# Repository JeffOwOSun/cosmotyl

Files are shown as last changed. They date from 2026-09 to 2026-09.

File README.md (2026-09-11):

# Cosmotyl

A Python + OpenSCAD generator for a split ergonomic keyboard with curved,
floating key plates, a three-key thumb pod, and a flat base with screw columns.
The default layout has **29 keys per half**: 26 finger keys and 3 thumb keys.

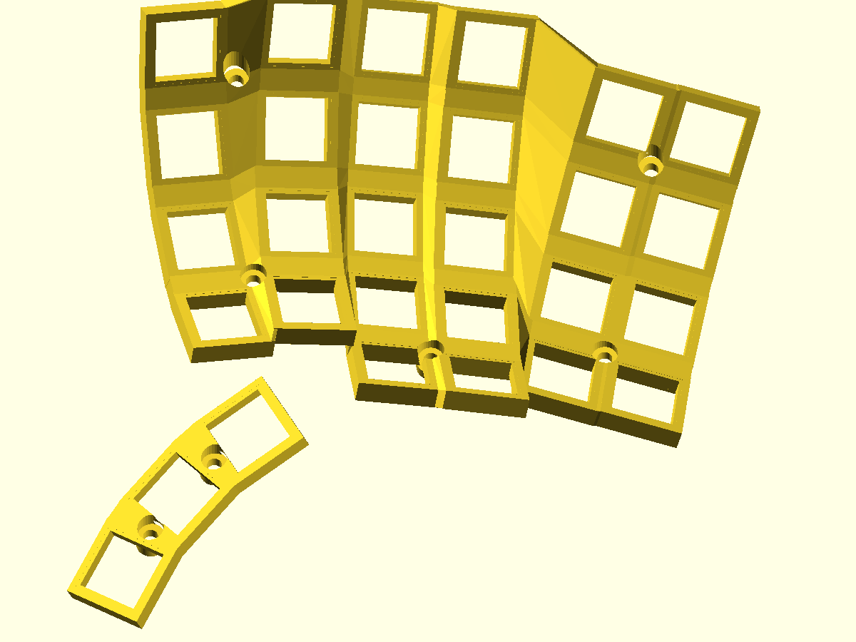
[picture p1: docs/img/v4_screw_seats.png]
Cosmotyl v4 repaired screw seats


The current v4 design prints as three parts per half: a finger sheet, a thumb
pod, and a base. Each screw recess has a continuous 3.4 mm thick bearing pad;
matching columns end 0.15 mm below the pad. The generated and exported meshes
pass closed-surface, bearing-seat, switch-envelope, screw-head, and assembly
interference checks. See [validation notes](docs/validation.md).

This remains a prototype: electronics mounting, wrist-rest integration, and
physical print/assembly trials are unfinished. The overhang heuristic still
flags one patch on the finger sheet. Earlier v1 and v3 source generators are
kept for reference; their obsolete STL exports have been removed.

## Explore the design

Download or clone the repository and open
[`output/keywell_viewer.html`](output/keywell_viewer.html) in a WebGL-capable
browser. It embeds the meshes and three.js and works offline. Drag to orbit,
scroll to zoom, and use the controls to inspect the parts, mirrored left half,
switch envelopes, and thumb placement geometry. Top and base have separate
toggles. GitHub's HTML file view shows source; download the file to run it.

## Generate

Python 3.10+ is required. The v4 mesh pipeline uses Manifold and NumPy to
preserve solid topology through Boolean operations and binary STL export.
The build evaluates the same literal geometry it writes to SCAD. OpenSCAD is
optional for inspecting that SCAD and required for the historical v1/v3 builds.

From the repository root:

```bash
python3 -m venv .venv
source .venv/bin/activate
python3 -m pip install -r requirements.txt
python3 src/verify.py          # keycap collision and bay headroom checks
python3 src/main4.py --fast    # check layout and write SCAD, no renderer needed
python3 src/main4.py           # mesh v4, verify seats/clearances, split print parts
python3 src/gen_viewer.py      # rebuild the offline viewer
python3 src/gen_viewer.py --prebuilt # use only the published example meshes
python3 -m unittest discover -s tests -v
```

Generators write working SCAD/STL files beside the sources in `src/`; these
are ignored by Git. The viewer prefers these fresh meshes and falls back to
prebuilt files in `output/`. After changing the layout, regenerate v4 before
rebuilding the viewer.
`--prebuilt` uses the checked-in example meshes exclusively.

Historical builds require OpenSCAD on `PATH`, in the standard macOS app
location, or configured through the `OPENSCAD` executable path:

```bash
python3 src/main3.py --fast    # omit --fast to render the v3 body
python3 src/main.py --fast     # omit --fast to render v1 case/base/wrist
python3 src/main.py --preview # also render preview PNGs (display required)
```

## Customize

Edit [`src/config.py`](src/config.py). All dimensions use millimeters and
angles use degrees. The canonical right half has +X toward the pinky, −Y
toward the user, and +Z upward.

- `COLUMNS`: column position, splay, travel, and row count.
- `THUMB`: anchor offset, orientation, fan radius, and angular spacing.
- `CASE`: tent, slope, lift, socket dimensions, and base thickness.
- `BATTERY` and `WRIST`: legacy bay probes and wrist-rest dimensions.

The preset derives from hand measurements adjusted for geometric clearance.
Raw traces and personal comfort analysis are excluded; the design dimensions
remain to reproduce the supplied model. See the
[measurement method](docs/hand_geometry_report.md).
The v4 screw sites in `main4.py` assume the included column layout and must be
reviewed when changing the column or row counts.

Each column follows a circular arc with radius `clamp(travel * 1.4, 55, 75)`.
Splay changes orientation while the home-row position stays on its target.
Global tent and slope are applied before a calculated floor-clearance lift.
The thumb keys follow a manually tuned 85 mm circular fan about a wrist-side
pivot; the viewer exposes its anchor, offset, plane, and spokes.

## Printing and assembly

The included v4 meshes are:

| File | Purpose |
|---|---|
| [`base4_right.stl`](output/base4_right.stl) | Base, flat side down; seven integral columns |
| [`top4_print_board.stl`](output/top4_print_board.stl) | Finger sheet rotated onto its side |
| [`top4_print_pod.stl`](output/top4_print_pod.stl) | Thumb pod rotated onto its side |
| [`top4_right.stl`](output/top4_right.stl) | Both upper parts in assembly coordinates |

Mirror the right-hand parts in the slicer for a left half. Inspect overhangs
and bed contact in the slicer before printing: the area/patch checks are
heuristics, and one patch on the finger sheet remains unresolved.

The modeled hardware per half is 29 MX-style switches with XDA caps and seven
3.0 × 12 mm thread-forming screws with pan heads. Screws enter from above
before switches are installed; columns have 2.5 mm pilot bores and 6 mm necks.
The 6 mm counterbores have uninterrupted bearing rings around the 3.4 mm
clearance holes. Screw-head seats are lowered 0.4 mm from the original design.
Use the updated base together with the updated upper parts.
Check actual switch and screw dimensions against the model. The legacy
battery envelope is 50 × 35 × 6.5 mm with a XIAO-class controller; the v4 base
does not yet contain physical electronics pockets or mounts.

## Checks and limitations

- `verify.py` rejects collisions in a simplified two-slab keycap OBB model
  and inadequate sampled bay headroom. It does not model every real keycap.
- Full v4 builds require empty intersections for top/switch, base/switch,
  top/base, and all seven screw heads against the switch/cap/travel envelope.
  A 0.05 mm envelope clearance is cut into the upper sheet. `--fast` skips mesh
  checks. Historical builds still reject OpenSCAD errors and warnings.
- The exporter checks every edge for closure and consistent winding before
  and after splitting the top into two print files. Vertical material probes
  check all seven bearing rings, clear shafts, and the matching column seats.
  CI checks the published files and performs a complete v4 build.
- Orientation and flat-down patch audits report potential print issues; they
  do not establish that a printer can produce the part without supports.
- The v1 wrist rest is not fitted to the v4 base. No dedicated left STLs,
  electronics integration, wiring layout, PCB, or firmware are provided.

## Source map

| Module | Role |
|---|---|
| `config.py`, `placement.py`, `transform.py` | Parameters, key frames, matrix math |
| `main4.py` | Current base, screw seats, upper sheet, print export and audits |
| `main3.py`, `main.py` | Earlier rod-supported and walled variants |
| `web.py`, `skirt.py`, `bottom.py` | Plate connections and legacy case geometry |
| `wrist.py`, `electronics.py` | Legacy wrist rest and electronics features |
| `verify.py`, `devtool.py`, `render.py` | Layout checks, switch envelopes, legacy OpenSCAD rendering |
| `mesh_backend.py`, `mesh_audit.py`, `stl_io.py` | Robust CSG evaluation, topology/seat checks, binary STL I/O |
| `stl_components.py`, `stl_clean.py` | Mesh component inspection and sliver removal |
| `gen_viewer.py`, `viewer.css`, `vendor/` | Offline viewer generation |

`docs/` contains historical design and research notes, including abandoned
experiments. Their older verdicts are not current verification results.

The retained `devtool_right.stl` is the switch-envelope inspection asset used
by the offline viewer and validation; it is not a printed part.

## Acknowledgments

The research notes study [Cosmos Keyboards](https://github.com/rianadon/Cosmos-Keyboards),
[Dactyl](https://github.com/adereth/dactyl-keyboard), Dactyl-Manuform, and
Dometyl placement and geometry approaches. Their names and source references
are retained in the notes. Cosmotyl is an independent project.

The mesh pipeline uses [Manifold](https://github.com/elalish/manifold) for
solid modeling. The viewer vendors three.js r147 under MIT; its full notice is in
[`src/vendor/three.LICENSE.txt`](src/vendor/three.LICENSE.txt) and embedded in
the generated HTML. See [third-party notices](THIRD_PARTY_NOTICES.md).

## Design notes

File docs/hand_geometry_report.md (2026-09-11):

# Layout preset and measurement method

The default in [`src/config.py`](../src/config.py) is a scan-derived example
layout. Its design dimensions are retained so the included meshes can be
reproduced. Raw hand traces and personal comfort analysis are not distributed.

Each finger trace was approximated by a line to estimate column position,
splay, and comfortable travel. Those inputs were adjusted for keycap clearance
before becoming the column table. Travel controls the bounded bowl radius and
column height; it is not a guarantee of reach or comfort for another hand.

To customize the layout, edit `COLUMNS`, `THUMB`, and `CASE` in `config.py`,
run the geometry checks, and inspect the generated model. The thumb fan is a
manually tuned circular approximation. Physical fit and print quality still
need to be checked on a prototype.

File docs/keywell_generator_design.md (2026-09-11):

# Keywell Generator — Architecture & Design

> Historical design notes. Some experiments and referenced artifacts are not
> included in this repository; see the root README for the current build.

A standalone Python → OpenSCAD procedural generator for the Cosmotyl split keyboard,
replacing Cosmos (whose rounded walls + wrist-rest solid are PRO-locked). Design follows
your 8-step pipeline, with every default traced to a source: **[C]** Cosmos internals
([cosmos_internals.md](research/cosmos_internals.md)),
**[M]** Dactyl Manuform, **[D]** Dometyl
([generator_patterns.md](research/generator_patterns.md)),
**[U]** our scan/collision-verified values
(gen_case.py (historical artifact, not included)).

## Core architectural decisions

1. **Stack**: Python emitting OpenSCAD (like your Clojure→scad experience; OpenSCAD is
   already installed and `gen_case.py` proves the workflow). Pure-functional style:
   placement math returns 4×4 matrices; solids are emitted separately.
2. **The one non-negotiable pattern — place/position duality [M]**: a single function
   `key_frame(col, row) -> Mat4` feeds BOTH solid placement and point queries
   (`key_position(col, row, local_pt) -> Vec3`). Thumb anchor, screw sites, wall starts,
   wrist footprint, USB port — all consume this one function, never re-derive. This is
   manuform's `apply-key-geometry` trick and the reason its thumb follows the well
   automatically.
3. **Coordinates [C]**: mm, degrees, **Z-up**, right-handed; key local frame +Z out of
   the cap; each key frame lands at **socket top center**. Right half canonical, left =
   mirror. (This drops gen_case.py's y-up design frame — one frame end to end, no
   rotate([90,0,0]) at the tail.)
4. **Hollow shell (Charybdis-style)**: NO vertical extrusion of the keywell perimeter.
   The case = thin web shell (thickness ≈ socket height) + swept perimeter walls only
   where structurally needed + interior pillars that double as heat-insert bosses.
5. **Rich intermediate results [D]**: each stage returns geometry + metadata (wall foot
   quads, continuous `outline`/`inline` ground paths). The bottom plate and wrist rest
   are then ~10-line consumers of the outline — never modeled independently.

## The 8-step pipeline, concretely

### 1. Ground the home row
World origin = home-row key of the **middle column**, socket top center, cap facing +Z.
Every other key is placed relative to this. (Cosmos centers on `centerRow = nRows-3`,
same idea [C§1]; manuform `centerrow = nrows-3` [M].)

### 2. Grow the fingers cluster
Per-column dataclass `Column{name, offset(x,y,z), splay, radius_or_travel, rows}` —
layout-as-data, dometyl `Lookups` style [D§7.2]. Placement for key (c, r):

```
key_frame(c,r) = Splay_c · T(offset_c) · ArcRow(r - home_row)
ArcRow(k):  R_c = clamp(1.4·travel_c, 55, 75)            [U, scan-derived]
            Δθ_c = max(18.5/R_c, 18.9/(R_c - 7))          [U, collision-verified]
            rotate -k·Δθ_c about X through [0, 0, R_cap], R_cap = R_c + cap_top
```

- Pivot about the **finger-contact sphere** (`+ cap_top` on the radius): cap_top = 6.2
  (MX unpressed) + 9.9 (XDA) ≈ 16.1 mm [C§2] (Clojure uses plate 4 + SA 12.7 = 16.7 [M]).
- **Splay rotates about the cluster origin** (cumulative γ), not the column's own axis
  [C§2] — this is what Cosmos does and what our `inject_splay.py` already encodes.
  Values: +10.7 / +4 / 0 / −1.5 / −11.4 / −11.4 (non-negotiable).
- Column staggers from your hand scan (gen_case.py L9-16 table, re-expressed in Z-up).
- Row curvature is per-column via `Δθ_c` (deeper bowl for longer fingers), replacing
  fixed α=15°; no cross-column arc — columns are placed by offset+splay like [U]/[D],
  not on a second sphere.

### 3. Grow the thumb cluster (pointing into the ground is fine)
Anchor **through the pipeline** [M§2.2], never absolute:

```
thumb_origin = key_position(inner_col, bottom_row, [+w/2, -h/2, 0]) + tuned_offset
thumb_frame(i) = T(thumb_origin) · Rz(yaw) · Ry(roll) · Rx(pitch) · T(key_i_offset)
```

Seed pose = the Cosmos Curved-3 pose we already ship, converted into this anchored form
(Cosmos values: (−35.78, −25.67, −7.08) mm / (−11.9°, −24.8°, 34.4°) [C§3], plus our
(−4, −6, 0) nudge). 2 keys initially (matching the accepted design), sculpt table
available for more.

### 4. Orient: tenting + backward rotation — applied ONCE
`Orient = T(0,0,lift) · Ry(-tent) · Rx(-slope)` applied at the single tail of
`key_frame` [M§6], so every point query inherits it. `tent = 12°` canonical.
`lift` is **computed**: scan all socket/cap corner points, `lift = clearance − min_z`
[D§6] — no magic z constants. Unlike Cosmos, the thumb is anchored (step 3), so
re-tenting moves it correctly for free — fixing Cosmos's tent-slider-ignores-thumb wart.

### 5. Thin shell: curved plate + minimal lofted skirt (NO walls) — per your call
- **Web (the case itself)**: 0.1 mm corner posts + triangle-hulls between
  row/col/diagonal neighbors [M§3] (gen_case.py already does this); thickness = socket
  height 4.7 mm [C§7], top flush with socket top. The doubly-curved 4.7 mm plate is the
  structural shell — no perimeter walls, no vertical extrusion of the keywell.
- **Support skirt**: a thin ruled loft from the plate's boundary edge straight down to
  the z=0 construction plane — each boundary edge segment hulled with its own floor
  projection (this degenerates dometyl's bezier sweep to d1=d2=0; the foot outline
  falls out for free). Thickness 2 mm; its only jobs are (a) a flat printable rim,
  (b) carrying the USB-C slot, (c) hosting the insert bosses, (d) hiding electronics.
  Boundary detection: flat-project socket corners → concave hull [C§6], or directly the
  known edge list from the grid (gen_case.py `boundary_edges`).
- **Pillars**: vertical struts from web underside to floor at the heat-insert sites
  (step 6) + under the thumb pod — pillars ARE the bosses, no separate ribs.
- **Rounded top edge**: with no wall band, this reduces to rounding the plate's exposed
  boundary edge — chamfer/roundover ring swept along the boundary loop (cheap,
  printable, no minkowski of the whole solid).
- **Thumb↔body seam**: explicit configurable link (universal hard part [D§7-pitfalls]);
  v1 = triangle-hull bridge like gen_case.py L169-174, kept as its own module; the
  thumb pod gets its own skirt loft to the same plane.

### 6. Bottom plate — a projection, aligned by construction
`plate = linear_extrude(2.5) polygon(outline_2d)` where `outline_2d` = the skirt's foot
outline recorded in step 5 (dometyl `Connect.outline` [D§5.3]; equivalently manuform's
`cut` at z≈0 [M§5.2]). Heat-insert bosses (M3: bore Ø4.0 for insert, boss Ø8, h 6)
placed along the skirt's inner foot path; the plate's screw holes reuse the **same site
list** — alignment is guaranteed because both consume one data structure. 5 sites:
back-left, back-right, front-right, front-middle, thumb-side. (Resolved: 5× M3 heat
inserts, per your OK.)

### 7. Electronics in the BASE, not the shell
- **XIAO nRF52840** bay: PCB 21×17.8×3.4 (+USB-C overhang ≈1.3); printed rails on the
  bottom plate hold it; USB-C slot (9.5×3.6, chamfered) cut through the back skirt at a
  height computed from `key_position` of the back boundary edge — one port per half,
  no TRRS (your accepted design).
- **Battery** pocket sized for your actual cells (screenshots): **EEMB LP603449
  49×34×6.0 mm 1100 mAh** (design driver) and **522332 32×22×5.2 mm 400 mAh** (fits the
  same pocket). Pocket 50×35×6.5 with a strap bar + JST-PH 2.0 pigtail channel,
  positioned under the middle-column web where step-2 clearance analysis
  (gen_case.py L108-132 shows ≥ bay height) says it fits.
- Both live on the bottom plate → swap/repair without reprinting the shell.

### 8. Wrist rests — with real clearance
Port Cosmos's OPEN footprint algorithm [C§5]: case-side edge from actual wall outline
points, front edge = `min_y + extension (80 mm)`, taper 10°, maxWidth 100. Then the two
things Cosmos can't do:
- **`clearance` parameter = 1.0 mm**: offset the case-side edge away from the case along
  the local outline normal before building the solid — pad drops in/out freely.
- Solid generation ourselves (PRO in Cosmos): extrude footprint, apply slope 5° + WR
  tent 6° [C§5 defaults], `minkowski` a small sphere on the top face for the rounded
  comfortable edge, flat bottom.
- Pad ends at the **middle-column line** (your earlier requirement), position seeded
  from the accepted (+52, 0, −18) offset.

## Defaults table (provenance-tagged)

| Parameter | Value | Src |
|---|---|---|
| Key pitch (row, arc chord) | 18.5 mm | U |
| Cap-base clearance rule | Δθ = max(18.5/R, 18.9/(R−7)) | U |
| Column radius | clamp(1.4·travel, 55, 75) | U |
| cap_top (MX + XDA) | 6.2 + 9.9 = 16.1 mm | C |
| Splay (inner→outer) | +10.7, +4, 0, −1.5, −11.4, −11.4 | U |
| Tent / lift clearance | 12° / computed, ≥ 8 mm interior | U |
| MX cutout | 14.15 mm (print shrink) + 1.4 mm clip undercut | U |
| Socket (plate) size | 18×18, height 4.7 mm | C |
| Web thickness | = socket height (4.7) | C |
| Skirt thickness | 2 mm (ruled loft, boundary → z=0) | you |
| Boundary edge roundover | r 1.5 mm ring along boundary loop | D (adapted) |
| Bottom plate | 2.5 mm | D (1.65) → thicker for bays |
| Heat inserts | M3, bore Ø4.0, boss Ø8×6; 5 sites | M/C, OK'd |
| Battery pocket | 50×35×6.5 (LP603449; 522332 fits) | you |
| Wrist ext / taper / maxW / slope / WR tent | 80 mm / 10° / 100 mm / 5° / 6° | C |
| **Wrist↔case clearance** | **1.0 mm** | **you** |

## Module layout (`scratch/keywell/`)

```
config.py      # dataclasses: Column, Thumb, Case, Wrist — the whole design as data
transform.py   # Mat4 helpers (from gen_case.py), frame composition
placement.py   # key_frame / key_position / thumb_frame + lift computation
verify.py      # OBB keycap collision (ported), bay clearance, skirt-foot sanity
web.py         # posts + triangle-hulls
skirt.py       # ruled loft boundary→plane, foot outline, edge roundover
bottom.py      # plate from outline, bosses, screw holes
electronics.py # XIAO rails + USB slot + battery pocket
wrist.py       # footprint + clearance offset + solid
emit.py        # SCAD emission; scene = union of parts
main.py        # build right half, mirror left, render STLs, run verify
```

## Verification plan (each iteration)

1. `verify.py` gates: 0 keycap OBB collisions; bay clearances ≥ spec; every skirt foot
   lands at z=0; outline is simple (no self-intersections).
2. `openscad -o` renders both halves + plate + wrist → STLs into the working directory.
3. Rebuild the three.js viewer from the new STLs (existing `gen_cosmos_viewer.py`
   pipeline) → visual check with screenshots, including the 1 mm wrist gap measured on
   a cross-section (existing junction-section tool).

## Resolved decisions (2026-09-10)

1. **Shell style**: NO walls — curved plate + minimal 2 mm skirt lofted to the z=0
   construction plane, purely for a flat printable bottom (your call).
2. **Fastening**: 5× M3 heat inserts, OK'd.
3. **Battery**: EEMB LP603449 (49×34×6.0, 1100 mAh) drives the pocket; 522332
   (32×22×5.2, 400 mAh) fits the same pocket (your screenshots).

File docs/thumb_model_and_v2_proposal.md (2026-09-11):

# Thumb Placement Model + v2 Pipeline Proposal

> Historical design notes. Some experiments and referenced artifacts are not
> included in this repository; see the root README for the current build.

Deliverable for feedback items #4–#6 (2026-09-10). Sources: [thumb_placement_models.md](research/thumb_placement_models.md) (Dactyl/Manuform/Dometyl/Cosmos source analysis, file+line cited) and [thumb_kinematics_web.md](research/thumb_kinematics_web.md) (biomechanics + community literature).

## 1. The thumb placement model (#4)

**Recommendation: a planar circular fan arc about the CMC pivot, anchored through the finger pipeline.** This is simultaneously the biomechanically correct model and the one the best-engineered generator (dometyl) uses.

Why this is the right curve, not just a convenient one:

- With the palm planted, pure thumb flexion–extension is rotation about ONE fixed axis in the trapezium (Hollister et al. 1992), so the thumb tip traces a **circle** — the anatomically exact curve for a key row reached by the cheapest 1-DOF motion.
- The exact anatomical refinement (two skew axes, ~124° apart, ~9.2 mm offset) collapses to the same circle within <1.5 mm over a 3-key sweep, so nothing fancier is justified.
- Comfortable sweep radius from HCI research: **63–76 mm** (CHI 2014 thumb-area studies); dometyl ships R = 85; our scan's straight-looking 42 mm trace is consistent with any R ∈ [70, 100] (sagitta at R = 85 over 42 mm is only 2.6 mm — below trace noise).
- Every project that beats hand-tuned offsets uses exactly this: dometyl's fan (R = 85, 14.4°/key about a fixed center), Cosmos `placeOnSphere` (same thing plus dome curvature), Keyboardio's physical "thumb arc".

### The expression

**Anchor — derived through the pipeline, never absolute** (the Manuform/Cosmos pattern; this is what makes the cluster follow stagger/curvature/tent changes automatically):

$$A = M_{\text{index,bottom}} \cdot T(-29, -30, 0)$$

where \(M_{\text{index,bottom}}\) is the world frame of the index-column bottom key and (−29, −30) mm is **your measured thumb-rest offset** from the hand scan.

**Cluster frame** (heading measured, tilts converged from 3 projects):

$$F = A \cdot R_z(-37°) \cdot R_y(\beta_t) \cdot R_x(\alpha_t) \cdot T(0,0,z_t)$$

with your measured −37° arc heading; β_t = −25° roll toward the thumb pad (Manuform −23…−35°, Cosmos Curved −24.8°, dometyl −20° all converge here); α_t = +10° pitch; z_t = −7 mm drop.

**The curve** (in frame F, arc center on the palm side approximating the CMC pivot):

$$C(\theta) = \big(R\sin\theta,\; R(1-\cos\theta),\; 0\big), \qquad R = 85\text{ mm (tunable 70–100)}$$

**Moving frame + key poses**: tangent \(\hat T(\theta) = (\cos\theta, \sin\theta, 0)\), normal \(\hat N\) pointing at the arc center, binormal \(\hat B = \hat z_F\):

$$M_i = F \cdot [\hat T(\theta_i) \mid \hat N(\theta_i) \mid \hat B \mid C(\theta_i)] \cdot R_{\hat T}(\rho_i), \qquad \theta_i = (i - i_{\text{home}}) \cdot p / R$$

with key pitch p = 20 mm (current thumb pitch) → 13.5°/key, matching dometyl's 14.4° and the biomechanical 14.6° at R = 75. Optional cup roll ρ_i = −10°·(i − i_home) tilts outer keys toward the pad (upgrade path = Cosmos dome).

**Sanity checks built in**: 3-key span = 2p = 40 mm ≤ your measured 42 mm comfortable span; total sweep 27° ≤ 35° budget (⅔ of the 53° FE range of motion); home key at the rest pose θ₀, not mid-arc.

**Free parameters and their status**: measured — anchor (−29,−30), heading −37°, span budget 42; defaulted-but-bounded — R = 85 ∈ [70,100], β_t = −25°, α_t = +10°, z_t = −7, ρ = 0. The devtool collision gate + your visual review tune the last four.

## 2. Connector generation by sweep (#5)

Exactly your procedure, expressed against C(θ). Right-half frame (mirror of your left-hand description — the innermost thumb key's inner face points toward **+x**/the main board):

1. Place thumb keys on C(θ), loft adjacent keys into a single row (pairwise hulls along \(\hat T\)).
2. Take the **inner side face** of the innermost key t0: the rectangle at local +HW spanning the socket depth and plate thickness.
3. **Sweep** that profile along C(θ) extended past θ₀ (toward the board): sample θ at 2–3° steps, place the profile with the moving frame at each sample, hull consecutive profiles.
4. Stop when the swept profile is fully inside the main body; **cut** the overlap (boolean subtract body), keeping the sweep watertight against it.
5. Loft/fillet the seam ring where the sweep meets the body.

Because the sweep follows the same curve the keys sit on, the connector is tangent-continuous with the thumb row by construction — no more misaligned loft between unrelated frames (the current index→pod hulls).

## 3. v2 pipeline (#6) — Bezier-surface body

Restating your algorithm with implementation specifics:

| Step | What | Implementation notes |
|---|---|---|
| A | Solid (hole-less) socket blocks at every key pose (fingers + thumb on C(θ)) | trivial change: today's plates without the hole cut |
| B | Loft into a continuous reference solid | today's hull machinery, but between full blocks → every face continuous; this reference defines the **bottom** and the minimum top |
| C | Bezier control net: one control curve per column (control points at that column's socket centers + normal offset), rows roughly x-aligned; tensor-product patch evaluated on a dense grid → polyhedron | pure Python; no CGAL needed for surface eval |
| D | Thumb cluster columns join the net as additional control columns (via C(θ) frames) | the surface flows over the connector region — this is what makes the seam smooth |
| E | Verify surface ≥ reference top everywhere (sample reference top corners against patch; push control points up where violated); body = volume between patch and B's bottom | iterate until zero violations |
| F | Cuts in order: (1) flat mount pocket per key (key_w × key_d, normal to key frame, down to socket-top plane — restores the flat seat + the ~1.5 mm clip thickness MX needs), (2) 14.15 through-hole + clip undercut, (3) bottom hollow | pocket before hole, exactly as you specified |
| G | Gate: `intersection(body, devtool) = ∅` where devtool = switches + XDA caps + 4 mm travel envelopes + underside housings/pins | already built and running — today's build reports **CLEAN** |

**No walls at all** (#2): the v2 body is a thick curved slab — the skirt disappears. Consequences to sign off on: M3 bosses become pillars hanging from the slab underside to the bottom-plate plane; the XIAO + USB port mount moves to the **bottom plate** (cradle already lives there; the slot becomes a notch in the slab's back edge or a bottom-plate-mounted port); the bottom plate keeps the current foot-polygon outline.

## 4. Already done this session (items #1–#3)

- **3-key thumb**: config + web + skirt generalized; build is green with 0 keycap collisions.
- **Devtool**: switches + caps + travel envelopes render as a translucent red toggle in the [viewer](../output/keywell_viewer.html), and the build now runs the intersection gate — currently **CLEAN** (even the ugly seam doesn't invade any switch/cap volume; it's an aesthetic/printability problem, which v2's surface fixes properly).

## Decision requested

1. **Thumb model**: planar fan arc as specced (R=85 default, pipeline anchor, your scan's −29/−30/−37°) — OK to implement?
2. **v2 pipeline**: proceed with A–G as tabled, replacing the current web+skirt entirely?
3. **Electronics relocation** (consequence of no-wall): XIAO/USB on the bottom plate, bosses as underside pillars — OK?

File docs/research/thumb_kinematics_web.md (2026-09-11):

# Thumb Motion Models for 3-Key Thumb Cluster Placement — Web Research

> Historical design notes. Some experiments and referenced artifacts are not
> included in this repository; see the root README for the current build.

Research date: 2026-09-10. All web-sourced; inline URLs per claim. Confidence notes marked where a number comes from secondary summaries rather than the primary paper text.

## 1. Accepted kinematic model of thumb-tip motion

**The consensus biomechanical model treats the trapeziometacarpal (CMC/TMC) joint as 2 rotational DOF about two FIXED, NON-ORTHOGONAL, NON-INTERSECTING (skew) axes**, established by Hollister, Buford, Myers, Giurintano & Novick, *"The axes of rotation of the thumb carpometacarpal joint"*, J. Orthop. Res. 10(3):454–460, 1992 ([paper via Google Scholar](https://scholar.google.com/scholar?q=%22The+axes+of+rotation+of+the+thumb+carpometacarpal+joint%22+Hollister)). Their key findings:
- The **flexion–extension (FE) axis is fixed in the trapezium**; the **abduction–adduction (AA) axis is fixed in the first metacarpal**; neither axis is perpendicular to the bones or to each other ([PubMed summary](https://pubmed.ncbi.nlm.nih.gov/?term=Hollister+axes+rotation+thumb+carpometacarpal)).
- Follow-up modeling literature quantifies the skew as an inter-axis angle of ≈124° (SD ≈19°) with an inter-axis offset of ≈9.2 mm (numbers from later studies building on Hollister's method, surfaced in an NIH-indexed source during search — treat as representative, verify against the specific paper before publishing). Because the axes are fixed and skewed, the articular surfaces behave like **"skewed tori"** rather than an orthogonal saddle.
- The joint additionally exhibits coupled **pronation–supination (axial rotation)**: Cooney, Lucca, Chao & Linscheid, *"The kinesiology of the thumb trapeziometacarpal joint"*, JBJS 63-A(9):1371–1381, 1981 ([Scholar](https://scholar.google.com/scholar?q=Cooney+kinesiology+thumb+trapeziometacarpal+joint+1981)) measured average TMC ROM of **53° flexion–extension, 42° abduction–adduction, 17° axial rotation** via roentgenographic markers. The 17° axial rotation is largely kinematically coupled to FE/AA (it is what lets the pad "oppose"), which matters for key-top orientation.
- Robotics confirms the skew-axis requirement: the CMU **ACT (Anatomically Correct Testbed) hand thumb** (Chang & Matsuoka, *"A Kinematic Thumb Model for the ACT Hand"*, ICRA 2006, [CMU RI page](https://www.ri.cmu.edu/publications/a-kinematic-thumb-model-for-the-act-hand/)) is a **5-DOF serial chain (2 CMC + 2 MCP + 1 IP) with deliberately non-orthogonal, non-intersecting axes**, and the same group showed that simplified orthogonal/intersecting-axis thumb models **mispredict the tip workspace and endpoint forces** — the direct argument for not modeling the thumb as a gimbal.

**What curve does the TIP trace with the palm planted?**
- Pure FE at the CMC (distal joints held) is rotation about ONE fixed axis, so the tip traces a **circular arc lying in a plane perpendicular to the FE axis**, with radius = perpendicular distance from tip to that axis. This is why circle/sphere fitting to motion-capture thumb-tip trajectories is a standard technique for locating the functional pivot and radius of curvature (e.g., sphere/circle-fitting of thumb-tip workspaces in reachable-workspace studies, [UCSF/eScholarship workspace modeling](https://escholarship.org/), [markerless mocap CMC studies on PMC](https://www.ncbi.nlm.nih.gov/pmc/)).
- **Plane orientation relative to the palm:** classical hand anatomy (Kapandji; standard kinesiology references, e.g., [OUHSC hand kinesiology notes](https://www.ouhsc.edu/bserdac/dthompso/web/namics/thumb.htm)) defines thumb **flexion–extension as occurring in a plane roughly PARALLEL to the palm** (thumb sweeps across the palm) and **palmar abduction–adduction in a plane roughly PERPENDICULAR to the palm**. So to first order the FE axis ≈ palm normal — but Hollister's result says it is oblique, tilted away from the exact palm normal and not orthogonal to the AA axis, so the real FE arc plane is **tilted ~10–25° from palm-parallel and the arc plane also rides ~1–2 cm above the desk when the palm is planted** (tilt magnitude is my synthesis of "non-orthogonal, non-perpendicular-to-bones"; the papers give axis orientations relative to bone landmarks, not the palm plane — a hand scan should FIT this tilt rather than assume it).
- Full 2-DOF **circumduction traces a cone-like closed loop**, i.e., the tip moves on an approximately spherical/toroidal shell around the CMC region ([PMC review of CMC kinematics](https://www.ncbi.nlm.nih.gov/pmc/), thumb-workspace modeling literature above). With skew offset axes the exact shell is a **torus patch** (offset d≈9 mm between axes), which for a 3-key cluster is indistinguishable from a sphere of radius R±d.
- **Quantitative tip-sweep radius from HCI research:** for one-handed phone grips, the comfortable thumb sweep is an **arc of ≈63–76 mm (2.5–3 in) radius about the thumb base**, with extreme reach measured up to **97.5 mm** (Bergström-Lehtovirta & Oulasvirta, *"Modeling the functional area of the thumb on mobile touchscreen surfaces"*, CHI 2014, [PDF via Aalto](http://users.comnet.aalto.fi/oulasvir/pubs/)); Steven Hoober's thumb-zone work popularized the arc-shaped "natural zone" ([uxmatters series](https://www.uxmatters.com/mt/archives/2017/03/design-for-fingers-touch-and-people-part-1.php)). These radii are measured mid-flexion (bent MCP/IP), which matches the typing posture better than full-extension anthropometric thumb length (~100–120 mm from CMC).

## 2. How ergonomic keyboard designers actually place thumb clusters

**Cosmos (ryanis.cool/cosmos)** — the most explicit generator:
- The webcam **hand scan measures only phalanx bone lengths** and drives keywell row/column stagger; the docs state the fitting algorithm is "primitive" and the **thumb cluster is NOT auto-placed from scan data** ([Cosmos hand-scans docs](https://ryanis.cool/cosmos/docs/hand-scans/)).
- Thumb presets: **Manuform, Carbonfet, Orbyl, Curved**; the **"Curved" preset with 3 or 5 keys is the recommended comfort option**, and users are told to experiment with **negative curvature** ([Cosmos docs / tips](https://ryanis.cool/cosmos/docs/)). The whole cluster is moved/rotated as a rigid unit (press "P"), i.e., placement is manual 6-DOF.
- **Expert mode is the quantitative core**: thumb keys are placed with `placeOnSphere({curvature, spacing, angle, row})`, which arranges keys **along concentric circles**: `angle` = position along the circle, `row` = number of `spacing` (mm) intervals from the sphere center, `curvature` = per-step tilt so key normals stay tangent to the sphere ([Cosmos expert-mode docs](https://ryanis.cool/cosmos/docs/expert/), source: [github.com/rianadon/Cosmos-Keyboards](https://github.com/rianadon/Cosmos-Keyboards)). Main keywell uses `placeOnMatrix` (two cylinder curvatures). This is exactly a spherical-cap parameterization of the thumb fan.

**Dactyl / Dactyl-Manuform:**
- Original Dactyl (Matt Adereth, [github.com/adereth/dactyl-keyboard](https://github.com/adereth/dactyl-keyboard), talk *clojure.core/typing* [YouTube](https://www.youtube.com/watch?v=uk3A41U0iO4)) places the thumb keys on a concave well generated in Clojure like the torus-section finger wells.
- Dactyl-Manuform (Tom Short, [github.com/tshort/dactyl-keyboard](https://github.com/tshort/dactyl-keyboard)) swaps in the ManuForm thumb cluster: **each thumb key gets an individual Euler rotation `[rx ry rz]` plus translation `[tx ty tz]` from a `thumborigin` anchor near the bottom inner index-column key** (with a small global `thumb-offsets` vector); typical per-key rotations in the source are in the **±10–25° range per axis** and offsets of order 10–60 mm. There is **no underlying curve model** — the six keys are hand-tuned poses, which is exactly the pain point your model would fix ([community explanation of the rotation/translation vectors, r/ErgoMechKeyboards threads](https://www.reddit.com/r/ErgoMechKeyboards/)).

**Bastard Keyboards (Skeletyl / Charybdis, [bastardkb.com](https://bastardkb.com/)):** deliberately ship **3-key thumb clusters** (Skeletyl, Charybdis Nano) on the rationale that only keys inside the thumb's no-stretch zone should exist, with layers (Miryoku) replacing key count; on Charybdis the cluster is co-placed with the trackball so the thumb transitions between ball and keys without hand movement ([bastardkb.com product/docs pages](https://docs.bastardkb.com/)).

**Keyboardio Model 01/100 ([keyboard.io](https://shop.keyboard.io/)):** 4 thumb keys per hand arranged **along an arc under the palm** ("thumb arc") sized so adjacent modifiers can be chorded by one thumb; rationale is offloading pinkies and echoing natural thumb sweep, but no published radius — the arc was tuned through physical prototyping (Jesse Vincent's design write-ups/interviews).

**Community consensus numbers** (r/ErgoMechKeyboards, kbd.news):
- Only **1–2 thumb keys are comfortable for high-frequency use; 2–3 max are reachable without stretch**; extra keys get demoted to rare functions ([community consensus threads](https://www.reddit.com/r/ErgoMechKeyboards/), [bastardkb rationale](https://bastardkb.com/)).
- kbd.news distinguishes two schools: **"thumb blocks"** (Kinesis/ErgoDox plates) vs **"thumb curves"** (Keyboardio, Kyria, Iris) that align few keys **along the thumb's arc**; sloped/dished clusters beat flat ones; most-used key should sit ≤0.5u from the thumb's resting spot; convex keycaps preferred because the thumb strikes obliquely ([kbd.news, tags "thumb cluster"/"ergonomics"](https://kbd.news/)).
- In **Ergogen** ([docs.ergogen.xyz](https://docs.ergogen.xyz/)), thumb fans are built with per-key `rotate` around a shared origin plus `splay` — i.e., a discrete circular arc in 2D, tented afterwards.
- Practical fit check: print layouts 1:1 with [compare.splitkb.com](https://compare.splitkb.com/) and see where the thumb lands.

## 3. Projects with EXPLICIT curve parameterizations
1. **Cosmos `placeOnSphere`** — spherical cap: key i at azimuth `angle_i` on circle `row_i · spacing` from center, normal tilted by `curvature · row` to stay sphere-tangent ([expert docs](https://ryanis.cool/cosmos/docs/expert/)). The only mainstream generator with a closed-form thumb curve.
2. **Original Dactyl** — thumb keys on the same torus/cylinder-section machinery as the keywell (row radius + column radius parameters in `dactyl.clj`, [source](https://github.com/adereth/dactyl-keyboard)).
3. **Ergogen splay/rotate zones** — 2D circular fan about a declared origin ([docs](https://docs.ergogen.xyz/)).
4. **Lalboard (JesusFreke, [github.com/JesusFreke/lalboard](https://github.com/JesusFreke/lalboard)) and its commercial successor Svalboard ([svalboard.com](https://svalboard.com/))** — per-finger/thumb clusters with **5–6-DOF adjustable mounts fitted empirically** (Svalboard publishes a 5-step fit procedure: palmrest 3-axis, then per-cluster X/Y/Z/roll/yaw); users have clay-molded or 3D-scanned hands to freeze positions. **No analytic curve** — it's measured-pose capture, the empirical endpoint your model should approximate analytically.
5. Dactyl-Manuform and most forks: **no curve**, hand-tuned per-key poses (see §2).

## 4. Proposed candidate mathematical models for a 3-key cluster

Common frame: palm plane Π with origin at planted pisiform/heel, x = ulnar→radial, y = distal, z = palm normal. Let P = CMC pivot (palpable at base of thenar eminence, ~ scaphoid tubercle).

**Model A — Single circular FE arc about an oblique CMC axis (recommended default).**
K(θ) = P + R·(cosθ·u + sinθ·v), where {u,v,n} orthonormal, n = FE-axis direction = Rz(β)·Rx(α)·ẑ (α,β = tilt of the arc plane away from palm-parallel; expect α,β ≈ 10–25° per Hollister's non-orthogonality, fitted not assumed). Keys at θ_i = θ0 + i·Δθ, i∈{0,1,2}, with chord spacing s: Δθ = 2·asin(s/2R). With s = 19.05 mm (1u) and R = 75 mm (mid comfortable sweep 63–76 mm, CHI 2014): **Δθ ≈ 14.6°, total sweep ≈ 29° — comfortably inside Cooney's 53° FE ROM**. Key normal: start from in-plane radial direction −(cosθ·u+sinθ·v), rotate about the local tangent by opposition/pronation angle ψ ≈ 30–60° so the cap faces the thumb pad (community "sloped cluster" + Cooney's 17° axial coupling ⇒ optionally ψ_i = ψ0 + (17°/53°)·(θ_i−θ0)). Pros: minimal parameters (P, R, n, θ0, ψ0), adjacent keys reached by pure 1-DOF flexion (cheapest motion), directly fittable by circle-fit to 5+ scanned tip points during a planted-palm sweep. Cons: assumes constant R (true only if MCP/IP posture held); ignores AA.
Scan needs: thumb-tip positions at 5+ poses of a comfortable planted-palm sweep, +1 nail-plane orientation.

**Model B — Spherical cap with twist (Cosmos-compatible generalization).**
K(θ,φ) = P + R·(sinφ cosθ, sinφ sinθ, cosφ) in the CMC frame; 3 keys either along one parallel (φ const → reduces to Model A) or 2+1 across parallels for an inner "tucked" key; normals radial; twist ψ(θ) as above. This is exactly `placeOnSphere(curvature = Δφ per row, spacing = R·Δφ, angle = θ)` ([Cosmos expert docs](https://ryanis.cool/cosmos/docs/expert/)), so output is directly usable in Cosmos. Pros: captures both DOF, supports later 4th/5th key. Cons: sphere center ≠ true pivot pair (skew axes), one extra fitted angle.
Scan needs: tip positions over a small 2-DOF patch (sweep + one abducted/adducted repeat).

**Model C — Hollister-faithful two-skew-axis torus.**
K(θFE,θAA) = Rot(A1,θFE)·[ Rot(A2,θAA)·(T0 − P2) + P2 − P1 ] + P1 with axis lines (P1,a1) fixed in trapezium/palm frame and (P2,a2) riding on the metacarpal, inter-axis angle ≈124°, offset ≈9.2 mm (§1 caveats), T0 = rest tip. 3 keys = samples at (θFE = {−Δ,0,+Δ}, θAA = 0). Pros: anatomically exact; predicts the tilted, slightly helical key line (twist emerges naturally instead of being bolted on). Cons: axes are NOT recoverable from a static hand scan — Hollister needed an axis-finder jig; you'd need video/mocap of an isolated sweep, and for 3 keys it collapses to Model A within measurement noise (offset 9 mm ≪ R 75 mm ⇒ tip-position difference <1.5 mm over a 30° sweep).

**Recommendation:** fit Model A from a 5-point planted-palm sweep (circle fit gives P⊥, R, n in one shot); expose Model B's φ as the upgrade path; treat Model C as validation-only. Sanity anchors: R ∈ [60, 95] mm, inter-key pitch 14–17°, total 3-key sweep ≤ 35° (≈⅔ of the 53° FE ROM), cluster plate pitched 30–60° from palm plane toward the pad, most-used key at the REST pose θ0 (not mid-arc) per community guidance.

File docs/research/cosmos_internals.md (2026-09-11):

# Cosmos Keyboard Generator — Internals Report

> Historical design notes. Some experiments and referenced artifacts are not
> included in this repository; see the root README for the current build.

Distilled from the local clone at `research/cosmos-full/` (geometry engine is open source;
only `src/lib/worker/pro-patch/` stubs throw). Citations are file paths within
`cosmos-full/` unless noted. This seeds a clean-room reimplementation, so numbers and
transform order are authoritative.

## 1. Coordinate system & units

- Millimeters, degrees, **Z-up**, right-handed. Key local frame: **+Z out of the keycap**.
- A key's transform lands at the **socket top center** (`keyHoleTrsf`,
  `src/lib/worker/geometry.ts` L931-961).
- World origin ≈ the center of the fingers matrix: `centerCol = nCols/2`,
  `centerRow = nRows - 3`.
- The floor is found **post-hoc**: the model is raised by
  `additionalHeight = -minZ + verticalClearance + screw headroom`
  (`geometry.ts` L978-1029). Nothing is designed "from the floor up."
- **RIGHT hand is canonical**; the left half mirrors tuples as
  `pos(x→-x)`, `rot(α, -β, -γ)` plus a `trsf.mirror`
  (`src/lib/worker/config.cosmos.ts` L969-1008).
- Serialized units (proto/URL): lengths ×10 (0.1 mm), angles ×45 (1/45°). Tuple codec:
  per-component zigzag, 1 byte if `u < 128` else 2-byte 14-bit pack, LSB-first into an
  int64 (reimplemented in our `inject_splay.py` / `retent.py`).

## 2. Key placement math

Full composition:

```
M_world = ClusterTrsf · placeColumn(col) · ColumnTrsf · placeRow(row) · KeyLocal
```

- Each pose tuple decodes as `T(pos) · Rz(γ) · Ry(β) · Rx(α)` — **X rotation applied
  first**.
- `placeRow`: sphere-tangent placement. Radius
  `R = V_SPACE/2 / sin(colCurv/2) + capTop`; rotate `-colCurv · row` about X through
  `[0, 0, R]` (`src/lib/worker/modeling/transformation-ext.ts` L309-332).
- `capTop` = unpressed switch height above socket top (**MX: 6.2 mm**,
  `src/lib/geometry/switches.ts` L10-31).
- Defaults: `H_SPACE = 21.5`, `V_SPACE = 20.5`, `rowCurv = 5°`, `colCurv = 15°`
  (`src/lib/worker/config.serialize.ts` L217-220).
- **Splay** = cumulative γ in the column-cluster rotation, rotating about the **cluster
  origin** (`config.cosmos.ts` L1016-1024) — not about the column itself.
- Stock staggers: middle `(0, +2.8, -4.0)`, pinky/outer `(0, -13, +6)`.
- Keys/columns serialize **deltas from the parametric pose** (`toCosmosClusters`,
  `config.cosmos.ts` L215-221), so a "0" tuple means "exactly parametric".

## 3. Thumb cluster

- Thumb keys carry **absolute world poses**.
- `calcClusterTrsf = thumbPose · fingerPosInv(flat) · fingerPos(3D)` cancels in 3D
  (`config.cosmos.ts` L586-594) → **the tent slider never moves the thumbs**.
- Curved preset pose: `(-35.78, -25.67, -7.08)` mm /
  `(-11.889°, -24.800°, +34.444°)` — equal to legacy `curvedThumb` constants
  (`src/lib/worker/config.ts` L939-944).
- Per-key sculpt table for curved thumbs: `config.ts` L1209-1293
  (3-key = topLeft + topRight + middleLeft).

## 4. Tenting / orientation

- Tenting is a rotation baked into the fingers-cluster transform; Euler order as above
  (`Rz·Ry·Rx`, X first). Retenting a serialized design = decode cluster tuple, adjust β,
  re-encode (our `retent.py` operator).
- Because thumbs are absolute (see §3), retent operators must transform thumb poses
  explicitly if thumbs should follow.

## 5. Wrist rest

- **Footprint algorithm is OPEN** (`wristRestGeometry`, `geometry.ts` L1658-1740):
  - Case-side edge = the actual wall points → conformal **by construction**. This is why
    Cosmos cannot give clearance between pad and case.
  - Front edge = `minY - origin.y + extension`; taper clamps at `middle ± 10mm`.
- Solid generation (slope/tenting application, `WR_TOLERANCE = 0.25`) is PRO-stubbed.
- Proto fields: f15 = position tuple (0.1 mm, default `(10, -110, 0)`); f9/f16 extension
  ×10 (default 80 = 8 mm... stored 80→8.0mm); f10 taper ×45 (450 = 10°); f11/f17 maxWidth
  ×10 (1000 = 100 mm); f12 angle ×45; f13 slope ×45 (225 = 5°); f14 WR tenting ×45
  (270 = 6°).

## 6. Wall / web algorithms (OPEN — steal wholesale)

- **Boundary**: flat-project socket corners → `cdt2d` Delaunay → `concaveman` concave
  hull with concavity 1.5 (`geometry.ts` L1061-1181).
- **Wall cross-section**: 7 points ti/to/mi/mo/ki/bi/bo with exact-thickness corrections;
  offsets `xOut = wallXYOffset`, `zOut = wallZOffset`, then vertical drop to floor
  (`wallCriticalPoints`, `geometry.ts` L198-344).
- **Web**: same triangulation as boundary; thickness = socketHeight
  (`src/lib/worker/model.ts` L215-290).
- PRO-stubbed (throw): rounded walls, wrist solid, stilts, plate art.

## 7. Constants worth keeping

| Constant | Value | Source |
|---|---|---|
| wallThickness | 4 mm | config defaults |
| wallXYOffset | 5 mm (ours: 7) | config defaults |
| wallZOffset | 15 mm | config defaults |
| plateThickness | 3 mm | config defaults |
| verticalClearance | 0.1 mm | config defaults |
| webMinThicknessFactor | 0.8 | model.ts |
| keyBase (xda) | 15.11 mm = 6.2 + 0.9·9.9 | switches/keycaps |
| mx-skree socket | 18×18×4.7; partBottom 18.7×18.7×7.5 | socketsParts.ts |
| keycap depths | xda 9.9 / dsa 7.9 / mt3-r3 10.7 | keycaps.ts |
| DISPARITY_MAGIC | 5.95545213 | geometry.ts |
| arc magic | 28.636 | geometry.ts |
| foot | Ø10 × 2.5, inset 6 | model.ts |
| screws | 7× M3 heat-insert, countersunk | config defaults |

**Ours** (collision-verified, `gen_case.py` L25-49): row pitch
`Δθ = max(18.5/R, 18.9/(R-7))`, R clamped 55–75; `base_y = -(travel - 34)·0.3`;
MX cutout **14.15 mm** (print-shrink compensated).

## 8. PRO gaps (what we must build ourselves)

- Rounded top/side walls (bezier or fillet sweep — the trigger for this pivot).
- Wrist-rest solid generation (footprint is open, §5).
- Stilts, plate art — not needed.

## 9. Serialization quick-reference

- Lengths ×10 (0.1 mm), angles ×45.
- Tuple: per-component zigzag; 1 byte if `u < 128` else 2-byte 14-bit pack; components
  packed LSB-first into int64.
- Keyboard field 12 = `rounded_flags` (`RoundedFlags{side: bit0, top: bit1}`,
  `cosmosStructs.ts`).
- Working codecs: our `inject_splay.py`, `retent.py`, `decode_cm.py`.

## 10. Recommended steals for the new generator

1. Sphere-tangent key placement with the `capTop` offset (§2) — pivot about the *finger
   contact sphere*, not the socket plane.
2. 7-point wall cross-section (§6) for exact wall thickness on slanted walls.
3. Flat-projection + cdt2d + concave-hull boundary detection (§6).
4. Explicit absolute thumb frames + a retent operator (§3/§4).
5. Wrist-rest footprint algorithm (§5) **with a new clearance parameter** — offset the
   case-side edge outward by `clearance` (user requires 1 mm). Cosmos cannot do this.
6. 0.1 mm / (1/45)° tuple codec only if URL parity with Cosmos is ever wanted.

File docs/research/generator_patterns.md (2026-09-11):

# Procedural Keyboard Generator Patterns: Dactyl, Dactyl Manuform, Dometyl

> Historical design notes. Some experiments and referenced artifacts are not
> included in this repository; see the root README for the current build.

Sources (all paths relative to `scratch/research/`):
- `dactyl-keyboard/src/dactyl_keyboard/dactyl.clj` (adereth original, 1266 lines, scad-clj)
- `dactyl-manuform/src/dactyl_keyboard/dactyl.clj` (tshort fork, 761 lines)
- `dometyl/lib/*.ml` (OCaml, OCADml/OSCADml)

## 1. KEY PLACEMENT PIPELINE

### 1.1 Shared constants (identical in both Clojure projects)
From `dactyl.clj` L12-19 / manuform L66-73:
- `keyswitch-width = keyswitch-height = 14.4` ("Was 14.1, then 14.25")
- `plate-thickness = 4`
- `mount-width = mount-height = keyswitch + 3 = 17.4`
- `sa-profile-key-height = 12.7`
- `cap-top-height = plate-thickness + sa-profile-key-height = 16.7` (dactyl L122, manuform L147)

Curvature defaults: `α = π/12` (15°, column-direction/row curvature, rotation about X), `β = π/36` (5°, row-direction/column curvature, rotation about Y) — dactyl L120-121, manuform L19-20 (comments: "curvature of the columns" / "curvature of the rows").

### 1.2 Radius formulas (the core "curved well" math)
The key sits on a circle whose radius is chosen so adjacent keycap tops just clear each other. Half the key pitch subtends half the step angle:

original dactyl (L123-128):
```
row-radius    = ((mount-height + 0.5)/2) / sin(α/2) + cap-top-height
              = 8.95/sin(7.5°) + 16.7  ≈ 68.57 + 16.7 ≈ 85.27 mm
column-radius = ((mount-width + 2.0)/2) / sin(β/2) + cap-top-height
              = 9.7/sin(2.5°) + 16.7   ≈ 222.38 + 16.7 ≈ 239.08 mm
```
The `+0.5` / `+2.0` are inter-key gap allowances. Manuform parametrizes them as `extra-height = 1.0`, `extra-width = 2.5` (L37-38) giving `row-radius ≈ 87.18`, `column-radius ≈ 244.81` (L148-153). The radius is measured to the **keycap top** (hence `+ cap-top-height`); the shape is translated down by the radius, rotated, translated back up — so rotation is about the cap-top arc centre, not the plate.

### 1.3 `key-place` transform order — original dactyl (`defn key-place`, L130-147)
For key at (column, row), applied to shape in this exact order:
1. `translate [0 0 -row-radius]`
2. `rotate (α * (2 - row)) [1 0 0]`   ← centre row hardcoded = 2
3. `translate [0 0 row-radius]`
4. `translate [0 0 -column-radius]`
5. `rotate (β * (2 - column)) [0 1 0]`  ← centre column hardcoded = 2
6. `translate [0 0 column-radius]`
7. `translate column-offset` — stagger table (L135-138): col 2 → `[0 2.82 -3.0]` (comment "was moved -4.5"), col ≥ 4 → `[0 -5.8 5.64]`, else `[0 0 0]`
8. GLOBAL TENT: `rotate (π/12) [0 1 0]` then `translate [0 0 13]` (L145-147)

`case-place` (L149-163) is the same pipeline with a fixed `column-offset [0 -4.35 5.64]`, used to position wall spheres at *fractional* column/row coordinates.

### 1.4 Manuform `apply-key-geometry` (L157-189) — the generalized version
```
column-angle = β * (centercol - column)          ; centercol = 3 (L22)
:standard  = translate(0,0,-row-radius) ∘ rotate-x(α*(centerrow-row)) ∘ translate(0,0,row-radius)
           ∘ translate(0,0,-column-radius) ∘ rotate-y(column-angle) ∘ translate(0,0,column-radius)
           ∘ translate(column-offset column)
then:      rotate-y(tenting-angle) ∘ translate(0,0,keyboard-z-offset)
```
Constants: `nrows=4, ncols=5` (L16-17), `centerrow = nrows - 3 = 1` ("controls front-back tilt", L21), `centercol = 3` ("controls left-right tilt / tenting", L22), `tenting-angle = π/12` (L23), `keyboard-z-offset = 9` ("original=9 with centercol=3; use 16 for centercol=2", L35). Column offsets (L28-31): col 2 → `[0 2.82 -4.5]`, col ≥ 4 → `[0 -12 5.64]` ("original [0 -5.8 5.64]"), else zero.

Two alternate column styles (L24-26, chosen `:orthographic` automatically when nrows > 5):
- `:orthographic` (L168-174): rotates by column-angle but *translates* columns instead of arcing them: x shift `-(column - centercol) * column-x-delta` where `column-x-delta = -1 - column-radius*sin(β) ≈ -22.34` (L154), z shift `column-z-delta = column-radius * (1 - cos(column-angle))` (L167). Avoids key collision for tall matrices.
- `:fixed` (L175-183): per-column absolute angle/x/z tables `fixed-angles = [10° 10° 0 0 0 -15° -15°]`, `fixed-x = [-41.5 -22.5 0 20.3 41.4 65.5 89.6]`, `fixed-z = [12.1 8.3 0 5 10.7 14.5 17.5]`, `fixed-tenting = 0°` (L49-52), "defaults roughly match Maltron". Comment admits: **"NOTE: THIS DOESN'T WORK QUITE LIKE I'D HOPED."** (L48).

### 1.5 `key-place` vs `key-position` — the key architectural trick
Manuform L191-212: `apply-key-geometry` is parametrized over `translate-fn`, `rotate-x-fn`, `rotate-y-fn`:
- `key-place` passes scad-clj's `translate`/`rotate` → returns a solid.
- `key-position` passes `(partial map +)` and pure 3×3 matrix functions `rotate-around-x` / `rotate-around-y` (core.matrix `mmul`, L197-209) → returns a coordinate vector.

Same layout code produces both geometry and raw points (used by `thumborigin`, `screw-insert`, `rj9-start`, `usb-holder-position`, `teensy-top-xy`). This is the single most reusable pattern for the Python port.

### 1.6 Dometyl placement (`lib/curvature.ml`, `lib/plate.ml`)
Curvature is a first-class value, not inline math. `Curvature.place` (curvature.ml L55-73):
- **well** (column curvature): `well_point = (0,0,radius)`; key i is rotated `angle * (i - centre_idx)` about X, `~about:well_point` (L43-47), after an optional per-key `tilt` about Y with `tilt_correction ~xrot ~tilt = xrot * tilt / -2.` (L32) to keep tilted columns (e.g. index) aligned.
- **fan** (row/thumb splay): `fan_point = (radius,0,0)`; rotate `-angle * (i - centre_idx)` about Z (L49-50).
- Combinators: `Curve`, `Custom (int -> Key.t -> Key.t)`, `PreTweak`, `PostTweak`, `Mix (int -> t)` (L25-30) — per-key escape hatches without abandoning the curve.

`Plate.make` (plate.ml L88-201): per-column `Lookups` record of functions `{offset; curve; swing; splay; rows; centre} : int -> _` (L5-64). Defaults: offsets col2 `(0,3.5,-6)` middle, col3 `(1,-2.5,0.5)` ring, col≥4 `(1,-22,9.5)` pinky, col0 `(-2,0,7)`; curvature ring `radius 37, angle π/4.5`, pinky `35, π/4.1`, col0 `45, π/6, tilt π/6.75`, else `46, π/6.3`; splay ring `-π/25`, pinky `-π/9`. Column x-spacing: `space = keyhole.outer_w + spacing` with `spacing = 1.` (L111-118). Column pipeline (L122-136): curve column → `yrot ~about:(centre_offset - off) tent` (tent about the centre column!) → rotate `(0, swing, splay)` about the column's centre-key origin → translate offset. Finally a global **lift** (L168-183): scan all key faces for the lowest z and translate everything up by `clearance - lowest_z` — replacing dactyl's magic `+13`/`+9` z offsets with a computed value.

## 2. THUMB CLUSTER

### 2.1 Original dactyl (`defn thumb-place`, L239-262)
Mini curved well with its own radii (`row-radius = ((mount-height+1)/2)/sin(α/2)+16.7 ≈ 87.18`, `column-radius = ((mount-width+2)/2)/sin(β/2)+16.7 ≈ 239.08`), then a hand-tuned rigid transform:
1. row arc about X (`rotate (α*row)`, no centre offset), 2. column arc about Y (`rotate (column*β)`), 3. `translate [mount-width 0 0]`, 4. `rotate (π*(1/4 - 3/16)) [0 0 1]` = π/16 = 11.25° yaw, 5. `rotate (π/12) [1 1 0]` — 15° about the *diagonal* [1 1 0] axis, 6. `translate [-52 -45 40]`.
Layout uses fractional grid coords: 2×2u keys at `(0,-1/2)`, `(1,-1/2)`; 1u at `(1,1)`, `(2,-1)`, `(2,0)`, `(2,1)` (`thumb-layout` L276-280). Anchor is absolute — if the main well moves, `[-52 -45 40]` must be re-tuned by hand.

### 2.2 Manuform (`thumborigin`, L291-293)
```
thumborigin = key-position(1, cornerrow, [mount-width/2, -mount-height/2, 0]) + thumb-offsets
thumb-offsets = [6 -3 7]  (L33)
```
i.e. the bottom-right corner of key (col 1, cornerrow) computed **through the full placement pipeline** — the cluster follows the well automatically. Six named per-key place fns (L296-347), each `rotate-x(deg) ∘ rotate-y(deg) ∘ rotate-z(deg) ∘ translate(thumborigin) ∘ translate(per-key offset)`:
- `thumb-tr-place`: (10°, -23°, 10°), `[-12 -16 3]`
- `thumb-tl-place`: (10°, -23°, 10°), `[-32 -15 -2]`
- `thumb-mr-place`: (-6°, -34°, 48°), `[-29 -40 -13]`
- `thumb-ml-place`: (6°, -34°, 40°), `[-51 -25 -12]`
- `thumb-br-place`: (-16°, -33°, 54°), `[-37.8 -55.3 -25.3]`
- `thumb-bl-place`: (-4°, -35°, 52°), `[-56.3 -43.3 -23.5]`
Top two use `larger-plate` (1.5u) and dedicated `thumb-post-*` at `±mount-height/1.15` (L382-385).

### 2.3 Dometyl (plate.ml L138-166)
Thumb is just another `Column` with fan curvature (default `radius 85, angle π/12.5`, Lookups.thumb L54-63), then: `Columns.zrot (-π/2)` ("orient along x-axis") → `Columns.rotate thumb_angle` (default `(π/20, -π/9, π/12)`) → `Columns.translate thumb_offset` (default `(-14, -42, 13.5)`) → tent `yrot ~about:(centre_offset - thumb_origin) tent` so the thumb tents around the same pivot as the body. Reuses all column machinery (curvature, joins, walls).

## 3. WEB / CONNECTORS

Identical technique in both Clojure projects (dactyl L187-233, manuform L240-285):
- `web-thickness = 3.5`, `post-size = 0.1`, `post-adj = post-size/2 = 0.05`
- `web-post` = 0.1×0.1×3.5 cube translated `[0 0 plate-thickness - web-thickness/2]` so its **top face is flush with the plate top** (z=4) and it hangs 3.5 down.
- Corner posts inset by `post-adj`: `web-post-tr = translate [mount-width/2 - 0.05, mount-height/2 - 0.05, 0]`, and `-tl/-bl/-br` mirrored (dactyl L194-197).
- `triangle-hulls` (manuform L252-255): `(apply union (map (partial apply hull) (partition 3 1 shapes)))` — hull every consecutive **triple** of posts, producing a triangle strip.

Three enumeration loops in `connectors` (manuform L257-285):
1. **Row connections** (col c ↔ c+1): `[(c+1,r).tl, (c,r).tr, (c+1,r).bl, (c,r).br]`
2. **Column connections** (row r ↔ r+1): `[(c,r).bl, (c,r).br, (c,r+1).tl, (c,r+1).tr]`
3. **Diagonal**: `[(c,r).br, (c,r+1).tr, (c+1,r).bl, (c+1,r+1).tl]` — one quad per 4-key intersection.
Because posts are ~0-size, hulls produce clean skirts whose top surface interpolates plate tops. Thumb connectors are the same posts hulled in hand-written sequences (dactyl `thumb-connectors` L303-380, manuform L387-458, incl. the thumb↔body seam via long triangle-hulls chains).

Dometyl replaces posts with **face hulls**: `Column.make` (column.ml L65-111) hulls the actual north/south face paths of adjacent keys (`Mesh.hull (face1.path @ face2.path)`, with ±0.01 "fudge faces in for union" translations, L58-63) and stores each join's west/east side sheets in `Join.t` for later reuse. Cross-column gaps use `Bridge.keys`/`Bridge.cols` (bridge.ml L22-125): each face is slid outward along its normal by `d1 = 0.5`, `d2 = 1.0` (`slide`, L6-9) and inward by `in_d = 0.2`, then hulled — the code comments explain d1/d2 exist for switch clearance ("If it is too large, it will interfere with needed switch clearance (like amoeba, hotswap)", L11-15) and TODO suggests replacing them with an automatic angle-sharpness check (L17-21).

## 4. WALLS (most important section)

### 4.1 Original dactyl: sphere-skinning (L405-743)
No generic wall function. Walls are built by placing 1mm spheres (`wall-sphere-at`, L408-411; `wall-sphere-bottom`/`-top` parameterized 0..1 front↔back, L416-430) at **fractional** (column,row) coords via `case-place`/`thumb-place`, then hulling consecutive pairs while marching in steps `wall-step = 0.2` (front-wall L449-493, back-wall L495-542, right-wall L544-574 — which marches 0.01 steps and hulls `partition 2 1` pairs — left-wall L576-609, plus three thumb walls L611-734). Wall↔plate gaps are patched by hulling spheres against `web-post` corners. Full of magic coordinates (`1.6666`, `0.7`, `right-wall-column = last col + 0.55`, `thumb-back-y = 0.93`, L394-400). Verdict: precise-looking but unmaintainable; this is exactly what manuform and dometyl each replaced.

### 4.2 Manuform: `wall-brace` (L482-506) — the classic pattern
Constants (L40-42): `wall-z-offset = -15` ("length of the first downward-sloping part of the wall"), `wall-xy-offset = 5`, `wall-thickness = 2` ("originally 5").
```clojure
(wall-locate1 dx dy) = [dx*wall-thickness,            dy*wall-thickness,            -1]
(wall-locate2 dx dy) = [dx*wall-xy-offset,            dy*wall-xy-offset,            wall-z-offset]
(wall-locate3 dx dy) = [dx*(wall-xy-offset+wall-thickness), dy*(...),               wall-z-offset]
```
(dx,dy) is the outward unit direction of that wall segment (e.g. back wall `0 1`, right wall `1 0`, corners get two braces with the two directions). `wall-brace place1 dx1 dy1 post1 place2 dx2 dy2 post2` =
1. `hull` of 8 shapes: each post + its locate1/2/3 offsets under both places → the sloping top wall band;
2. `bottom-hull` of the locate2 + locate3 shapes → drop to ground. `bottom` (L464-467) = `project` (2D projection) → `extrude-linear height` → translate to `z = height/2 - 10`; `bottom-hull` hulls the shapes with their 0.001-thick ground projections. locate2 vs locate3 differ by wall-thickness in xy, giving the vertical lower wall its thickness.
`key-wall-brace` (L504-506) just partials `key-place` for two key corners. `case-walls` (L508-583) enumerates: per-column back braces + between-column "tweener" braces, per-row right braces, left wall via `left-key-place` (key-position of col-0 left edge minus `[left-wall-x-offset=10, 0, left-wall-z-offset=3]`, L472-479), front wall, 7 thumb braces + 2 corner braces + 4 tweeners. The thumb↔body seam is hand-patched, flagged by the comment **"clunky bit on the top left thumb connection (normal connectors don't work well)"** (L553-582).
Ground trueing: final `model-right` subtracts `(translate [0 0 -20] (cube 350 350 40))` (L713) to shave anything below z=0.

### 4.3 Dometyl `lib/wall.ml` — bezier-swept walls from keyhole faces
A wall is generated from an actual key face (`Key.Face.t` = rounded path + corner `Points` + normal, key.ml L4-15), per side `` `North|`East|`South|`West ``. `Wall.make` (wall.ml L104-247), defaults `?(clearance=0.) ?(n_steps=`Flat 4) ?(min_step_dist=0.02) ?(d1=`Abs 14.) ?(d2=10.) ?(end_z=0.1)`:
1. **`swing_face`** (L90-102): quaternion-rotate the face about its bottom (or top, by normal z sign) edge so it becomes vertical — walls always start plumb regardless of key tilt.
2. **Clearance**: translate the swung face `clearance` along its normal (`cleared_face`, L119) — pushes wall start off the switch for cap/hotswap clearance; the gap is skinned back to the true face with 5 slices (L186-187).
3. **Quadratic bezier spine** (`bz`, L128-133): with `xy` = normalized horizontal projection of the face ortho:
   - `p1 = centre - 0.01*ortho` ("fudge for union")
   - `p2 = centre + xy * d1`  — d1 (`` `Abs mm `` or `` `Rel fraction`` of face height, L123-126) controls how far the wall shoots outward at start height;
   - `p3 = (centre.x, centre.y, end_z) + xy * d2` — d2 controls the ground landing offset.
4. **Steps**: `Steps.t = `Flat n | `PerZ mm` (L5-15) — `PerZ` gives one step per mm of face height (min 2), so short walls get few slices. `Util.prune_transforms ~min_dist:min_step_dist` drops profiles closer than 0.02 to the previous — the anti-self-intersection guard; if <2 remain: `failwith "Insufficient valid wall sweep transformations, consider tweaking d parameters."` (L177-180).
5. **Counter-rotation** (L134-141): a slerp'd quaternion, eased with cubic-bezier Easing (0.42,0)→(1,1), progressively cancels the face's z-tilt so the wall's angle matches the xy heading of its face.
6. **Scaling** (L145-163): optional `V2 (width, thickness)` taper along the sweep with optional easing (used for skeleton-style thinning walls).
7. **Two-pass end_z fix** (L164-172): sweep once with `end_z=0`, measure the min z of the last profile, re-run with `end_z` raised so the profile never dips underground; final mesh = clearing profiles + swept rows + `final` profiles skinned from the last row to its flat `V3.projection` (z=0) copy (L189-194) → the foot lands exactly on the ground plane.
8. **Rich return value** (L239-247): `{scad; key; side; start; cleared; foot; drawer; bounds_drawer}` — `foot : Points.t` is the ground-contact quad; `drawer : loc -> Path3.t` (L200-237) replays the wall's transform stack from any point on the start face (`` `TL|`BR|`T x|`XY (x,y)`` …) down to ground. Connect uses drawers to stitch neighbouring walls without re-deriving geometry.

Wall selection: `Walls.Sides.auto` (walls.ml L65-140) instantiates walls per side from lookup predicates (`north_lookup = const true`, `south_lookup i = i > 1`, `west_lookup i = i = 0`, `east_lookup = const false` defaults; thumb variants at L195-228), with per-side clearance overrides and separate index-column scaling. Manual mode takes explicit `int -> Wall.config option` maps.

Wall-to-wall gaps: `lib/connect.ml(i)` — `full_join` (morph start wall face into destination over `slices=12`, projecting pre-rotated faces when heading difference > `max_angle=1.4` rad) and `spline` (ground-level connector swept along a bezier spline of the walls' feet, with z-fillets, corner roundovers, `end_shrink=0.025`, and `tight_threshold`/`tight_d` fallback for sharp angles) (connect.mli L35-93). `skeleton`/`closed` presets assemble a full perimeter; the result `Connect.t = {scad; outline; inline}` (L6-11) records the continuous outer/inner ground outlines — consumed by bottom plate, eyelets, and tent. Doc comment: thumb links deliberately not auto-closed because sealing logic is "prone to breaking, which goes against dometyls philosophy of allowing easy repositioning/re-orienting of the thumb cluster" (connect.mli L160-164).

## 5. SCREW / INSERT MOUNTS & BOTTOM PLATES

### 5.1 Original dactyl
- `screw-hole` = cylinder r=1.5, h=60 (L1051-1053), subtracted at `key-place(4.5, 0.5)`, `key-place(4.5, 3.5)`, `thumb-place(2, -0.5)` (L1055-1059) — fractional grid coords again; same holes cut from both top and bottom parts so they align.
- Bottom is a *printed second shell*, not a flat plate: `bottom-plate` (L755-1049) re-runs the whole layout with `bottom-key-guard` cubes (mount-w × mount-h × 3.5 at z≈-4.5, L750-753), re-hulls all connections with posts shifted down `[0 0 -web-thickness-5]` (L772-776), re-hulls all wall spheres at `translate [0 ±1 1]`, and adds `stands` (L1018-1036): integrated feet = sphere r=(9.6+2)/2 hulled to ground (`bottom-hull`), minus a cube and a bumper-recess sphere (bumper Ø9.6, cut 1.5 above ground) at 4 key positions. Final parts are `difference`d with `(cube 1000 1000 10)` at z=-5 to flatten (L1207, L1221).

### 5.2 Manuform
`screw-insert-shape` (L640-642) = `cylinder [bottom-radius top-radius] height` + sphere cap at top — a heat-set insert boss. `screw-insert` (L644-656) computes xy via `key-position` + `wall-locate2/3` shifts so bosses embed in the wall band: `shift-up` rows use `wall-locate2(0,1) + [0 mount-height/2 0]`, `shift-down` `wall-locate2(0,-1) - ...`, `shift-left` `left-key-position + wall-locate3(-1,0)`, else right `wall-locate2(1,0) + [mount-width/2 0 0]`. Five sites (L658-664): `(0,0), (0,lastrow), (2,lastrow+0.3), (3,0), (lastcol,1)`. Constants (L665-670): height 3.8, insert bore Ø5.31→5.1 (tapered), boss = radii +1.6, height +1.5; through-plate screw holes r=1.7, length 350.
Bottom plate (L745-754): `(cut (translate [0 0 -0.1] (difference (union case-walls teensy-holder screw-insert-outers) screw-insert-screw-holes)))` — OpenSCAD `cut` takes the 2D cross-section at z≈0 of the wall bottoms → a laser-cuttable/printable flat plate that exactly matches the case footprint, with screw holes already in place. Zero extra bookkeeping — clever and worth stealing.

### 5.3 Dometyl
`lib/eyelet.ml`: `config = {outer_rad; inner_rad; thickness; hole}`, `hole = Through | Inset {depth; punch}`; presets `m4_config` (outer 5, inner 2.7, t 4, Through), `bumpon_config` (5.8/5/2.4, inset 0.6), `magnet_6x3_config` (4.4/3.15/4.6, inset 3.2 with `` `Rel 0.5`` punch) (L71-80). `Eyelet.make` (L84-159) builds the boss as a 2D outline: arc around the hole + two bezier "swoops" filleting into a run of wall points, extruded `thickness`; raises `failwith "Outline of eyelet ... contains intersections"` advising narrower feet or deeper bury. `Eyelet.place` (L161-199) positions it along the case's continuous `inline`/`outline` foot paths (closest-point or parameter `u`), `bury = 0.5` into the wall. `default_wall_locs` (L201-208): body W-first, N-2, N-last, S-3, thumb W-last. `Case.make` places eyelets after connections and `Eyelet.apply` adds boss + subtracts cut (case.ml L49-70).
`Bottom.make` (bottom.ml L43-113): plate = `Scad.polygon (Connect.outline_2d case.connections)` extruded `thickness = 1.65`, minus fastener holes at each eyelet centre — `Screw` counter-sunk via cone-scaled extrude (`scale = shaft_rad/head_rad`) or `Pan depth`, or magnet pockets — minus bump-on insets (rad 5.5, inset 0.8) located by key references `default_bumps = [thumb Last First; thumb Last Last; body First Last; body (Idx 3) Last; body Last Last; body Last First]` (L34-41), located via each key's actual face normals (L14-21). Bottom plate outline comes free from `Connect.t` — no re-derivation.

## 6. TENTING / ROTATION

- **Original dactyl**: tent = final `rotate (π/12) [0 1 0]` + `translate [0 0 13]` embedded (duplicated!) inside `key-place`, `case-place` (L145-147, L161-163), and differently inside `thumb-place` (`rotate π/12 [1 1 0]` + `[-52 -45 40]`). Flat bottom by boolean cut with a giant cube at z<0 (L1207/1221) — walls are simply built long enough to reach through the floor.
- **Manuform**: tent = `rotate-y tenting-angle` + `translate [0 0 keyboard-z-offset]` at the single tail of `apply-key-geometry` (L188-189), so key-place, key-position, thumborigin, screw positions, everything inherits it consistently. Ground: walls end via `bottom-hull` projections (already flat), plus the safety cut `translate [0 0 -20] (cube 350 350 40)` (L713).
- **Dometyl**: tent is a `Plate.make` parameter (`tent = π/12` default) applied per column as `yrot ~about:(centre_offset - column_offset)` (plate.ml L124-129) and to the thumb about the same pivot (L166) — i.e. rotation about the centre column so stagger tables stay meaningful; then the computed `lift` normalizes height to `keyhole clearance` (L168-183). Walls don't need a floor cut: the bezier sweep terminates at `end_z` and is skinned to its own z=0 projection (wall.ml L189-194). Additionally `lib/tent.ml` generates a **separate tenting base**: `Tent.make ?(degrees=20.)` rotates the case's `Connect` outline about the pinky-side bounding-box edge (auto-detected by comparing pinky home key to bbox edges, L228-244), builds a `Solid` shell or `Prison` of swept pillars between the flat and tilted outlines, re-drills fastener holes aligned to the case eyelets, and adds bump-on feet.

## 7. ARCHITECTURE LESSONS FOR THE PYTHON GENERATOR

**Worth copying:**
1. **Placement math separated from solid generation** (manuform `apply-key-geometry` L157-212). In Python: make the canonical placement a function `(col, row) -> 4×4 matrix`; apply it to solids *or* points. Every downstream feature (thumb anchor, screw sites, connector ports, wall starts) should consume matrices/points, never re-derive.
2. **Layout as data**: dometyl's `Lookups` (`int -> offset/curve/splay/rows`, plate.ml L5-64) and `Walls.Sides.auto` predicates (walls.ml L77-80) beat manuform's `cond` tables and beat dactyl's hardcoded loops. In Python: dataclasses of per-column config with callable or dict lookups + defaults.
3. **Rich intermediate results**: dometyl's `Wall.t` keeps `start/cleared/foot` points and a `drawer` closure; `Connect.t` keeps `outline/inline`; `Case.make` is literally `plate_builder → plate_welder → wall_builder → base_connector → ports_cutter` as injected functions (case.ml L33-78). The bottom plate is a 10-line function because the outline already exists. Design every stage to return geometry + queryable metadata, not just a mesh.
4. **Radius-from-pitch formula** `r = (pitch/2)/sin(θ/2) + cap_top_height` — keep it, it's the correct arc math; parametrize gap (`extra-width/height`) like manuform.
5. **Anchor derived positions through the pipeline** (manuform `thumborigin = key-position(1, cornerrow, corner) + offsets`), never absolute coords (dactyl `[-52 -45 40]`).
6. **Tiny-post + hull ("triangle-hulls")** is a robust, dumb, always-manifold gap filler (`partition 3 1` + hull). Good v1 strategy; dometyl-style face-path hulls with 0.5/1.0 mm slide-out clearance (bridge.ml `slide`) are the upgrade when you have real face paths.
7. **Wall recipe to adopt**: dometyl's — swing face vertical → clearance offset → quadratic bezier `(face centre) → (+d1·xy at start height) → (+d2·xy at end_z)` → sweep profiles with step pruning → skin last profile to its z=0 projection → record foot quad. `d1=14 abs / rel-to-height`, `d2=10`, `steps = PerZ(1mm)` are proven defaults. Manuform's locate1/2/3 (thickness 2, xy 5, z -15) is the simpler fallback and is fine for closed cases.
8. **Bottom plate via 2D projection/section of the walls at z≈0** (manuform `cut`, dometyl outline polygon) — never model it independently.
9. **Single tenting application point** and computed z-lift (dometyl's lowest-face scan) instead of magic z constants.

**Pitfalls the code itself admits:**
- Manuform L48: fixed column style "DOESN'T WORK QUITE LIKE I'D HOPED" — don't bother with absolute per-column pose tables; keep arc+offset.
- Manuform L553: "clunky bit on the top left thumb connection (normal connectors don't work well)" — the thumb↔body seam is *the* hard part in every generator; plan an explicit, configurable link (dometyl's `west_link`/`east_link` configs, and its stated philosophy of not auto-sealing thumb links, connect.mli L160-164).
- wall.mli L88-97: too many sweep steps → points bunch → self-intersecting mesh → CGAL failure; mitigations = `PerZ` steps, `min_step_dist` pruning, larger d1. Bake a min-profile-distance guard into any swept-wall implementation.
- connect.mli L67-77: high outline resolution + fillets → "bunching up of points" → self-intersection; sharp inter-wall angles need a reduced outward step (`tight_threshold`/`tight_d`).
- bridge.ml L11-21: clearance offsets (in_d/out_d) must be user-tunable because hotswap sockets/amoebas need room; TODO: derive from angle sharpness automatically.
- eyelet.ml L152-157: boss outlines can self-intersect on concave wall runs — validate and report with actionable messages like dometyl does.
- Original dactyl overall: fractional-coordinate sphere walls (L394-743) show what happens without a wall abstraction — hundreds of magic numbers; also global tent duplicated in 3 place functions drifted apart (`case-place` has different column-offset than `key-place`).

---
Key file citations recap: dactyl.clj L120-163 (placement), L187-233 (web), L239-262 (thumb), L405-743 (walls), L1051-1059 (screws); manuform L157-212 (apply-key-geometry/key-position), L291-347 (thumb), L482-583 (wall-brace/case-walls), L640-670 (screw inserts), L745-754 (plate via cut); dometyl wall.ml L90-247, curvature.ml L32-73, plate.ml L88-201, walls.ml L65-140, connect.mli, bridge.ml L6-125, column.ml L41-120, eyelet.ml L84-222, bottom.ml L43-113, tent.ml L215-346, case.ml L33-78.

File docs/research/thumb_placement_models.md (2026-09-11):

# Thumb Cluster Placement Models — Dactyl, Manuform, Dometyl, Cosmos

> Historical design notes. Some experiments and referenced artifacts are not
> included in this repository; see the root README for the current build.

All paths relative to `scratch/research/`. Every number below was re-verified against source this session.

## 1. Original Dactyl — mini spherical well + hand-tuned rigid mount

`dactyl-keyboard/src/dactyl_keyboard/dactyl.clj`, `thumb-place` (L239-262). The thumb is a second curved keywell with its OWN radii, then a rigid transform stack:

- α = π/12 (15°/key), β = π/36 (5°/key), cap-top-height = 4 + 12.7 = 16.7 (L120-122, L240-248).
- thumb row-radius = ((mount-height+1)/2)/sin(α/2) + 16.7 = (18.4/2)/sin 7.5° + 16.7 = 70.48 + 16.7 = **87.18 mm**; thumb column-radius = ((mount-width+2)/2)/sin(β/2) + 16.7 = 9.7/sin 2.5° + 16.7 = **239.08 mm** (mount-w = mount-h = 17.4).
- Per key (column,row), applied in order (L252-262):
  1. `T(0,0,−87.18)`, `Rx(α·row)`, `T(0,0,+87.18)`  ← rotation about the cap-top arc center ABOVE the key; note `α·row` (no center-row offset; rows are fractional: −1, −1/2, 0, 1)
  2. `T(0,0,−239.08)`, `Ry(β·column)`, `T(0,0,+239.08)`
  3. `T(17.4, 0, 0)`
  4. `Rz(π(1/4 − 3/16)) = Rz(π/16) = Rz(11.25°)`
  5. `R(π/12 = 15°, axis [1 1 0])` — 15° about the un-normalized diagonal
  6. `T(−52, −45, 40)` — ABSOLUTE anchor, hand-tuned, does not track the main well.
- Layout (L264-280): 2u keys at (0,−1/2), (1,−1/2); 1u at (1,1), (2,−1), (2,0), (2,1).

Model class: a true 2-axis arc grid (sphere-patch approximation, same math as the finger well) — keys DO lie on curves — but the cluster anchor is a magic constant.

## 2. Dactyl Manuform — pipeline-derived anchor + 6 free per-key poses (no curve)

`dactyl-manuform/src/dactyl_keyboard/dactyl.clj`:
- **Anchor** (L291-293): `thumborigin = key-position(1, cornerrow, [mount-width/2, −mount-height/2, 0]) + thumb-offsets`, with `thumb-offsets = [6 −3 7]` (L33), `cornerrow = nrows − 2` (L58-59: lastrow = nrows−1, cornerrow = lastrow−1). I.e. the BOTTOM-RIGHT CORNER of the index-adjacent column's corner key, computed through the full placement pipeline (`key-position` runs the same `apply-key-geometry` as solids, L191-212), so the cluster follows stagger/curvature/tenting changes automatically. This is the single most important pattern to copy.
- **Per-key** (L296-347), world = T(thumborigin + offset) · Rz · Ry · Rx (thread order: Rx first):
  | key | Rx | Ry | Rz | offset |
  |---|---|---|---|---|
  | tr | 10° | −23° | 10° | (−12, −16, 3) |
  | tl | 10° | −23° | 10° | (−32, −15, −2) |
  | mr | −6° | −34° | 48° | (−29, −40, −13) |
  | ml | 6° | −34° | 40° | (−51, −25, −12) |
  | br | −16° | −33° | 54° | (−37.8, −55.3, −25.3) |
  | bl | −4° | −35° | 52° | (−56.3, −43.3, −23.5) |
- No curve: 6 independent rigid poses. But note the regularity: Ry ≈ −23…−35° (roll toward thumb pad) and Rz grows 10→54° marching down the cluster — an implicit fan of ~11°/key in yaw.

## 3. Dometyl — the thumb IS a parametric curve (planar fan arc)

`dometyl/lib/curvature.ml` + `lib/plate.ml`:
- Thumb = one `Column` with **fan** curvature: default `radius = 85., angle = π/12.5 = 14.4°/key, centre = 1, 3 keys` (plate.ml L54-63).
- Fan math (curvature.ml L44, L49-50, L63-64): key i is rotated about the point `fan_point = (radius, 0, 0)` by `θ_i = −angle·(i − centre_idx)` about **Z** (plus optional per-key `yrot tilt`, default 0). Explicitly: `p_i = c + Rz(θ_i)(p − c)` with c = (85,0,0). For the default 3 keys: θ = {+14.4°, 0, −14.4°} → key origins (2.67, ∓21.14, 0) — a planar arc of radius 85 mm, chord pitch 21.1 mm.
- Cluster pose (plate.ml L138-166): fanned column → `Columns.zrot(−π/2)` ("orient along x-axis") → `Columns.rotate(thumb_angle)` with default `(π/20, −π/9, π/12) = (9°, −20°, 15°)` XYZ → `Columns.translate(thumb_offset)` default `(−14, −42, 13.5)` → tent `yrot ~about:(centre_offset − thumb_origin) tent` (same pivot as the body, so tenting carries the thumb consistently, L166).
- Curve parameterization: C(θ) = fan center + R·(direction), keys at equal Δθ; key +Z stays the fan-plane normal (fan rotates about Z only) — a **planar circular arc with keys normal to the plane**, the cleanest curve model of the four projects.

## 4. Cosmos — anchor derived through pipeline + 4 cluster generators (2 are curves)

`cosmos-full/src/lib/worker/config.ts`:
- **Anchor** `thumbOrigin(c)` (L900-958): `origin = [preset pose] · translateBy( placeOnMatrix(row = cornerRow−centerRow, column = 1−centerCol, merged finger curvature) transformed by upperKeysPlane(c) then translate(17.5/2, −17.5/2, 0) ) · Rz(staggerThumb.a) · T(staggerThumb.xyz)`; cornerRow = rows−2, centerRow = rows−3 (2.5/2 for 3/2-row boards), centerCol = cols/2 (L901-906). Same manuform idea: the anchor is the bottom-right quarter-key corner of column 1's corner key, run through the finger placement math incl. tenting plane (upperKeysPlane, L869-874). `approximateCosmosThumbOrigin` (L876-898) is the flat 21-mm-spacing version used by the editor.
- **Preset poses** prepended to that anchor (order = Rz·Ry·Rx world composition since ETrsf ops chain):
  - defaultThumb (manuform port, L933-938): Rx 28.868°, Ry 12.366°, Rz −47.284°, T(−42,−43,−8)+T(5,10,0) = T(−37,−33,−8)
  - curvedThumb (L939-944): Rx −11.890°, Ry −24.801°, Rz +34.450°, T(−35.783, −25.667, −7.083)
  - carbonfet (L911-915): Rx −9°, Ry 32°, Rz −160°, T(−26.2, −28.5, −8.9)
  - orbyl (L916-921): T(0,0,−8), Rx 10°, Ry −15°, Rz 5°, T(−57.75, −18.75, −2)
- **Per-key generators**:
  - `manuformThumbs` (L1077-1192): 6 free poses, e.g. topLeft Ry −3°, Rz 66°, T(−13.4, 17, −0.1); bottomRight Rx −21°, Ry −2°, Rz 106°, T(18.4,−18.5,−0.6). Ad-hoc offsets (Cosmos's re-tuned manuform).
  - `defaultThumbs` = curvedThumb (L1194-1325): each key = small trim rotation (e.g. topLeft Rx 17.8°, Ry 3.3°, Rz −8.2°) · `placeOnMatrix(fractional coords)` · z-trim. Fractional (column,row): topLeft (0.4,−0.34), topRight (1.43,−0.06), middleLeft (−0.72,−0.42), middleRight (0.29,0.67), bottomLeft (−0.64,−0.44), bottomRight (−0.75,0.58); curvature/spacing from user params (`thumbCurvature` L1340-1346, proto angles ×45, spacings ×10). So curved thumbs are keys on a 2-axis arc surface + per-key sculpt deltas.
  - `carbonfetThumbs` (L1356-1408): pure `placeOnMatrix` 3×2 grid, columns {−1,0,1}, rows {0.7,−0.3}, {0.575,−0.675}, {0.45,−0.8} — clean torus-patch placement, no per-key fudge.
  - `orbylThumbs` (L1410-1473): **keys on a sphere**: `placeOnSphere({angle, row})` at azimuth angles {80°, 130°, 180°, 230°}, row 1.85/2/2/2, spacing 18.75; plus trackball at center (Rz 30°, T(0,0,8)).
- **The curve/surface math** (`modeling/transformation-ext.ts`):
  - `placeOnMatrix` (L309-353): rowRadius = spacingOfRows/2/sin(curv_col/2) + capTop (MX capTop = 6.2); `t.rotate(−curv_col·row, about [0,0,+rowRadius], X)`; then columnRadius likewise and `t.rotate(−curv_row·column, about [0,0,+columnRadius], Y)`. Center ABOVE key plane → concave well.
  - `placeOnSphere` (L355-371): `R = spacing/2/sin(curv/2) + capTop`; `t.rotate(−curv·row, about [0,0,−R], X)` — center BELOW → **convex dome** — then `t.rotate(−angle)` about Z. Parameterization: polar angle φ = curv·row from the dome pole, azimuth ψ = angle. i.e. key(ψ,row) = Rz(−ψ)·RotX@(0,0,−R)(−curv·row). This is the most explicit "keys on a curved surface with a moving frame" of any generator.
- Thumb keys carry ABSOLUTE world poses after this; `calcClusterTrsf = thumbPose · fingerPosInv(flat) · fingerPos(3D)` cancels in 3D so the tent slider deliberately never moves thumbs (config.cosmos.ts L586-594, per our prior notes §3).

## 5. Cosmos hand-scan fitting — VERDICT: it does NOT place the thumb cluster

Dug hard; the premise "hand scan positions clusters from thumb metrics" is FALSE in the current code:
- The scan (`routes/scan`, `routes/scan2`, MediaPipe 21 landmarks) produces per-finger 4-bone kinematic chains: `calculateJoints` (`src/lib/hand.ts` L417-438) fixes the metacarpal (degree 0, `averageNorms` L194-205) and fits the phalange rotation axes by SVD/PCA of normalized bone vectors (`fitNorms` L215-243). Thumb DOF exception: 2nd joint 1-DOF, 3rd joint 2-DOF (header L19, L430-432).
- `HandFitView.svelte` — the only place scan data changes the CONFIG — computes **finger column staggers only**: FK with fixed curl angles [5°, 4°, 9°] accumulated over the 3 phalanges, `x = Σ lᵢ·cos(Σaⱼ)`, `y = −Σ lᵢ·sin(Σaⱼ)` (L20-36), staggers relative to index (L49-54), written into the fingers cluster (L72-77). The UI states verbatim (L122-126): "This does **not change** … anything about the **thumb cluster** (placement or spacing). You should tune those yourself using the Hand 3D model."
- What the scan DOES do for thumbs: the 3D preview solves the **inverse** problem — given the keyboard, pose the hand. `theBigFit` (`Viewer3D.svelte` L537-551) targets the 5 home keys (incl. `home: 'thumb'`); the wrist pose starts at the wrist-rest matrix (L489-510) and `refine()` (`handoptim.ts` L108-163) runs 300 iterations of gradient descent over the wrist **Euler angles only** (position stays fixed), minimizing per finger `E = (|R·x − t| − 0.99·(l₁+l₂+l₃))²` (linear branch when inside reach, L91-98) plus a joint-limit penalty on the MCP direction (L80-82); per-finger joint angles then come from the closed-form cyclic-quadrilateral IK `SolvedHand.ik` (`hand.ts` L263-308, `cyclicQuadAngle` L248-250 = law-of-cosines on the max-area inscribed quadrilateral).
- Takeaway: Cosmos's principled piece is the scanned thumb chain (CMC-anchored 4-bone chain with measured lengths + fitted axes) + an optimizer that can score reachability of any candidate cluster pose. Nothing maps scan → cluster pose in closed form.

## 6. Does anyone model the thumb as a curve?

| Project | Curve? | Parameterization |
|---|---|---|
| Dactyl | yes (2-axis arc grid) | Rx@(0,0,87.18)·(15°·row), Ry@(0,0,239.08)·(5°·col), fractional (col,row) |
| Manuform | no | 6 free rigid poses off a pipeline-derived anchor |
| Dometyl | **yes — planar fan arc** | rotate about (85,0,0) by −14.4°·(i−1) about Z |
| Cosmos manuform/default | no | free poses off pipeline anchor |
| Cosmos curved/carbonfet | yes (torus patch) | placeOnMatrix arcs, R = s/2/sin(κ/2)+6.2 |
| Cosmos orbyl | **yes — sphere/dome** | Rz(−ψ)·RotX@(0,0,−R)(−κ·row), ψ ∈ {80,130,180,230}° |

## 7. Our scan data (verified, hand_geometry_report.md)

- Thumb: "natural arc centered ~29 mm inward and ~30 mm below your index bottom row, running at ~37° from horizontal with ~42 mm of comfortable span (≈2–3 keys of arc)" (L15); Ergogen config uses `ref: matrix_index_bottom, shift: [−29, −30], rotate: −37` (L63-67).
- **No radius was measured**: `scratch/ergopad_analysis.py` L52 fits a LINE (slope → 37°), not a circle. A radius must therefore be assumed/inferred. Cross-check: at R = 85 mm (dometyl default), the sagitta over the 42 mm span is 85 − √(85² − 21²) = 2.63 mm — below trace noise, which is exactly why a line fit looked straight. So R ∈ [70, 100] is consistent with our data.

## 8. Recommended parametric model (synthesis)

**Anchor (verified inputs)**: derive through the finger pipeline, never absolute — `A = M_indexBottomKey · T(−29, −30, 0)` where M_indexBottomKey is the world 4×4 of the index-column bottom-row key from our generator (manuform/Cosmos pattern, §2/§4).

**Cluster frame (verified heading + inferred tilts)**: `F = A · Rz(−37°) · Ry(β_t) · Rx(α_t)` with β_t ≈ −25° (INFERRED: manuform −23…−35°, Cosmos curved −24.8°, dometyl −20° — all three converge on rolling the thumb plane ~20-35° so caps face the thumb pad) and α_t ≈ +10° pitch (manuform +10°, dometyl +9°). Drop z by ~−5…−8 mm relative to the corner key (manuform +7 on thumb-offsets but −13…−25 per key; Cosmos −7…−9; start at −7 and tune).

**Curve** — planar fan arc in the F frame (dometyl model, radius justified by our flat trace):
- C(θ) = (R·sin θ, R·(1 − cos θ)·σ, 0), θ ∈ [θ_min, θ_max], with R = 85 mm default (tunable 70–100), σ = +1 placing the arc center at (0, +R, 0) — on the palm side, approximating the CMC pivot, so the arc bows away from the palm like a real thumb sweep.
- Moving frame: T̂(θ) = (cos θ, σ·sin θ, 0); N̂(θ) = σ·(−sin θ, σ·cos θ, 0) (points at the arc center); B̂ = (0,0,1) = ẑ_F.
- Key i pose: `M_i = F · [T̂(θᵢ) | N̂(θᵢ) | B̂ | C(θᵢ)] · R_T(ρᵢ)` where θᵢ = (i − i_home)·p/R with pitch p and optional cup roll ρᵢ about the tangent (orbyl-style dome cupping; start ρ = 0, or ρᵢ = −10°·(i − i_home) to face keys toward the thumb pad — INFERRED, no project measured this).
- Constraint from scan: total span (n−1)·p ≤ 42 mm → 3 keys max — matches the report's "2–3 keys of arc" exactly.
- With curvature wanted later, swap B̂-constant for the Cosmos sphere: R_s = p/2/sin(κ/2) + capTop and rotate each key −κ·row about the local X through (0,0,−R_s) for a convex dome (κ ≈ 10°/key is Cosmos's orbyl example, model_gen/keyboards.ts L70).

**Validation loop (steal from Cosmos)**: implement the 4-bone thumb chain from hand.ts with OUR measured metrics and score each candidate (R, β_t, α_t, z) by reach error to the 3 key tops via the cyclic-quadrilateral IK — that turns Cosmos's visualization into the closed-loop cluster-placement optimizer they never built.

**Verified vs inferred summary**: verified — all formulas/numbers in §1-§6 (file+line cited), anchor (−29,−30), heading −37°, span 42 mm, 3-key budget; inferred — R = 85 (bounded 70–100 by sagitta argument), β_t = −25°, α_t = +10°, z = −7, cup roll ρ.

---
NOTE (parent): key correction to the task premise — Cosmos's hand scan feeds finger-column staggers and a hand-on-keyboard IK visualizer only; it does not position the thumb cluster (HandFitView.svelte L122-126 says so explicitly).

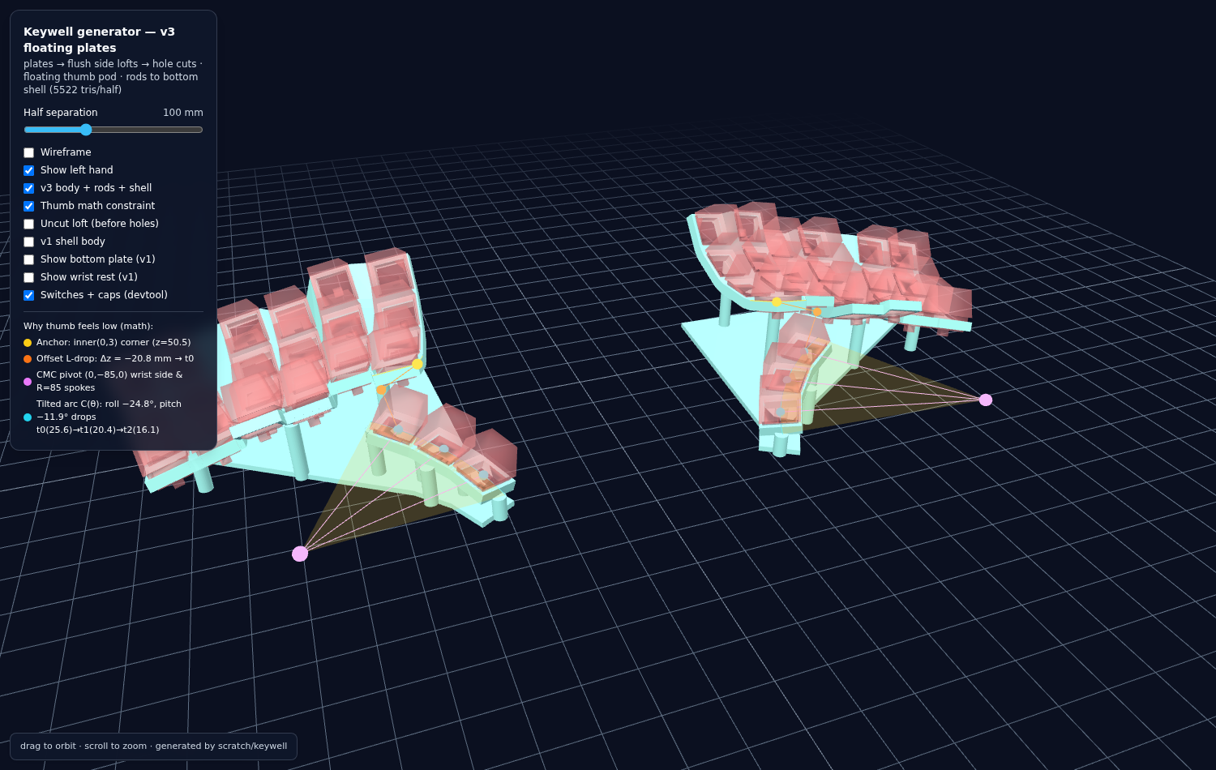
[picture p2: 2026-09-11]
docs/img/v3_math_viewer.png

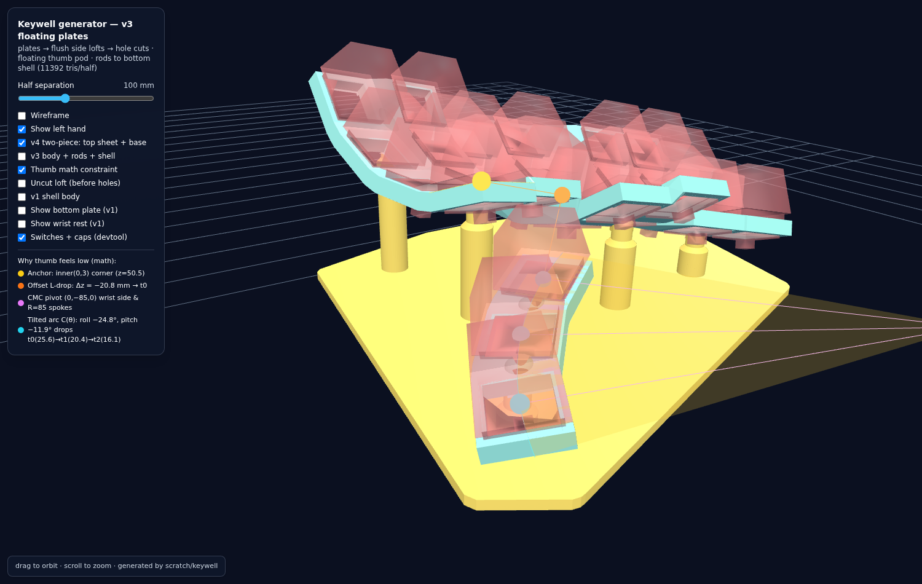
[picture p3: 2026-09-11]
docs/img/v4_closeup.png

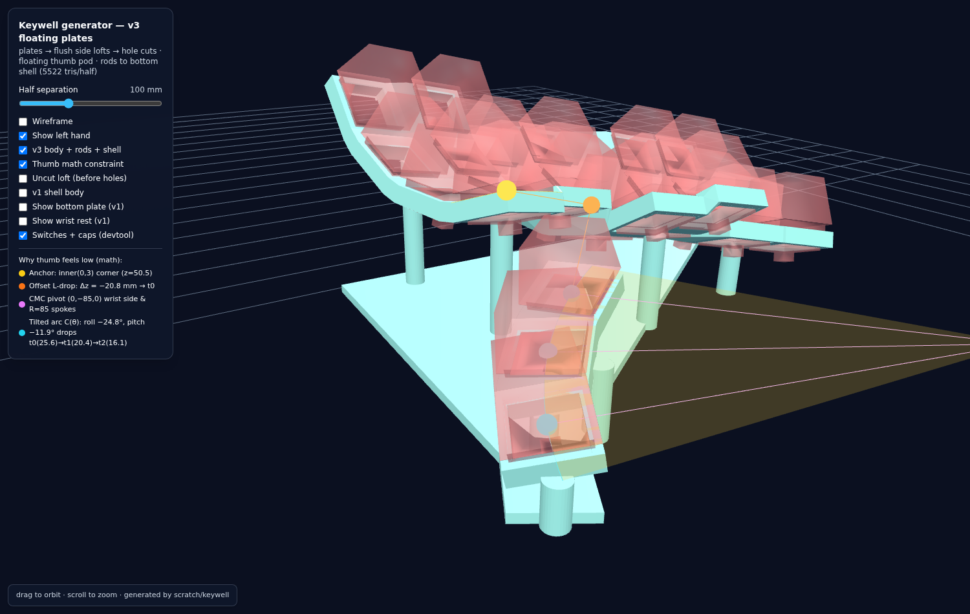
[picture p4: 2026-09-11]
docs/img/v3_math_closeup.png

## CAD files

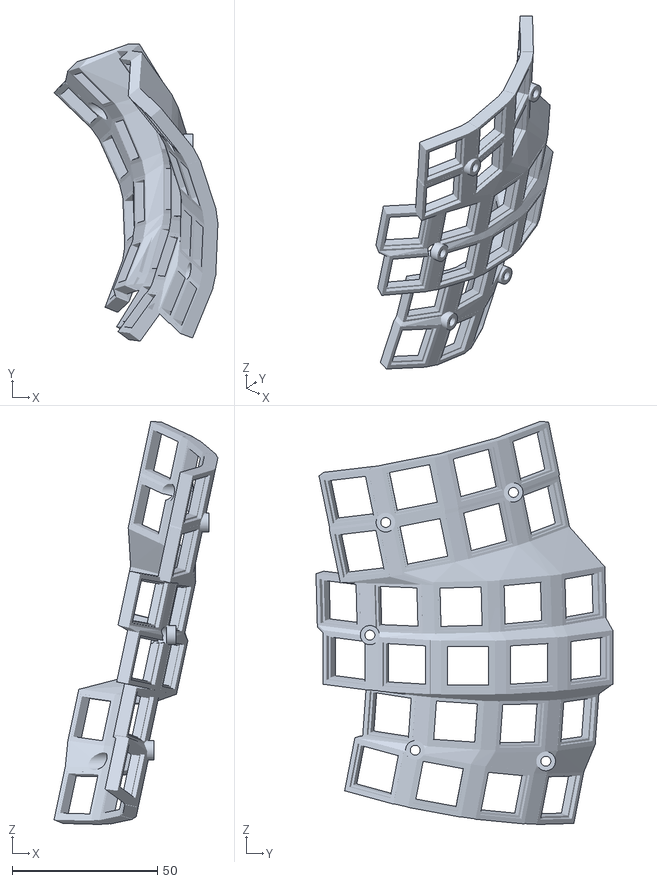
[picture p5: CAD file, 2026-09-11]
output/top4_print_board.stl
56.4 x 102.2 x 138.7

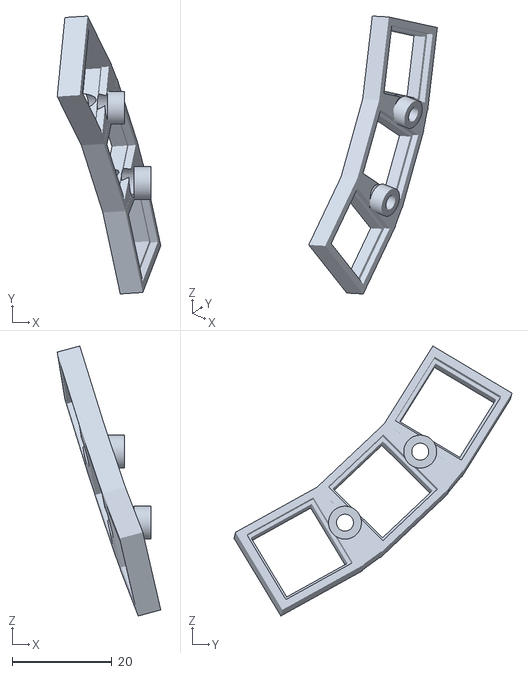
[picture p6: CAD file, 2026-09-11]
output/top4_print_pod.stl
20.8 x 55.7 x 54.1

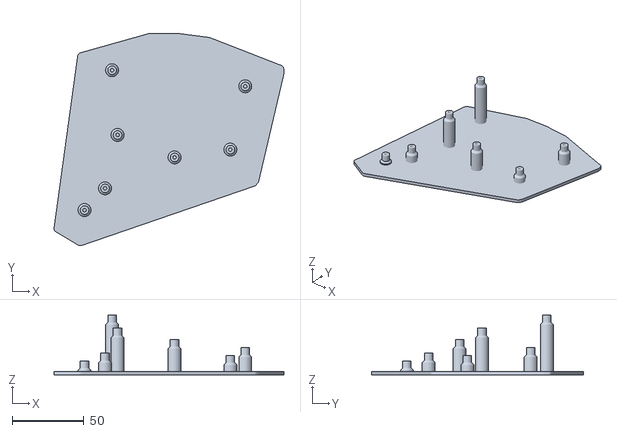
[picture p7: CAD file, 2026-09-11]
output/base4_right.stl
159.7 x 147.5 x 41.6

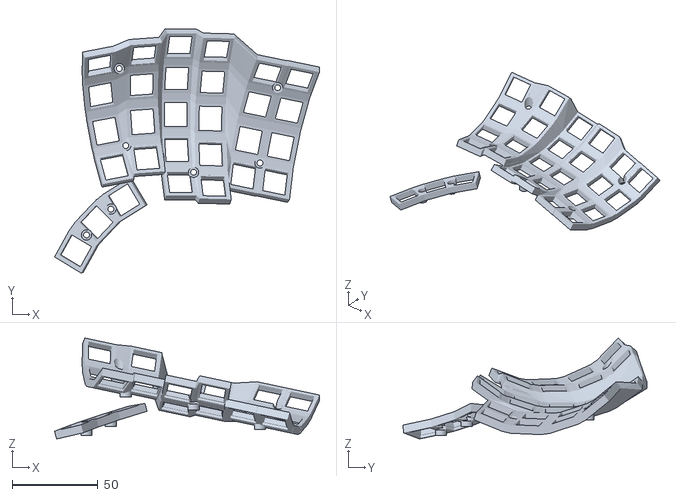
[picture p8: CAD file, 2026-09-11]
output/top4_right.stl
154.7 x 142.5 x 59.0

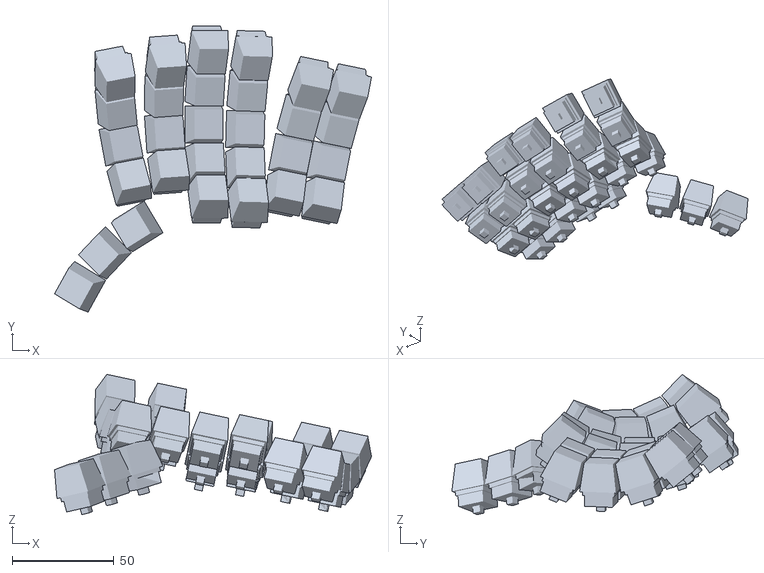
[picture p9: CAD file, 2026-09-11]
output/devtool_right.stl
155.8 x 140.7 x 68.9

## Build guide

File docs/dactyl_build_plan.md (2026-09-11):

# Dactyl Build Plan — Cosmos case + column flex PCBs + XIAO nRF52840

> Historical design notes. Some experiments and referenced artifacts are not
> included in this repository; see the root README for the current build.

Companion to the 3D case viewer (historical artifact, not included) and [hand geometry report](hand_geometry_report.md).

> [!IMPORTANT]
> **Update 2026-09-10 — own generator (keywell v1) supersedes the Cosmos path.** The new procedural generator in `scratch/keywell/` builds the whole right half from the hand scan: home-row sockets land exactly on scan targets, 0 keycap collisions (OBB-verified), no-wall shell (curved web plate + 2 mm skirt lofted to a flat z=0 rim), 5× M3 heat-insert bosses aligned to a countersunk bottom plate by construction, XIAO cradle + USB slot at the index column, 50×35×6.5 battery pocket (LP603449 / 522332), and a conformal wrist pad with a **verified ≥1.0 mm gap** ending at the middle-column line. Printables: keywell-caseright.stl (legacy mesh; regenerate from the historical source), keywell-plateright.stl (legacy mesh; regenerate from the historical source), keywell-wristright.stl (legacy mesh; regenerate from the historical source) (left half = slicer mirror); explore in the [keywell viewer](../output/keywell_viewer.html). The Cosmos design below remains the printable fallback.

## Layout (per hand, 29 keys)

- 4 rows × 6 columns (num / top / home / bottom)
- +2 keys in a 5th row under **middle, ring** only (the index one was traded for a thumb key)
- +3 thumb keys on your measured 37° arc, centered on the anchor

## Cosmos settings (transcribe into Advanced mode at [ryanis.cool/cosmos](https://ryanis.cool/cosmos/))

> [!IMPORTANT]
> **Update — FINAL design: tent 12°, stock thumb + nudge, fully clean.** The design is UI-rebuilt from stock Cosmos (Out column toggle, MX+Skree switches, XIAO BT MCU, wrist-rest widths 130/taper 5°) with the scanned per-column geometry (splay, stagger, curvature) injected at column level, plus a 7 mm wall offset. The thumb cluster is now the **stock "Curved, 3 keys" preset nudged (−4, −6, 0) mm** — the earlier byte-transplanted custom thumb is retired, because the stock pose plus that small nudge renders with **zero errors and zero warnings** while staying a factory preset. **Tenting caveat (upstream Cosmos behavior)**: the UI's Tenting Angle field rotates *only the keywell* — thumb clusters are serialized as absolute world poses (`calcClusterTrsf` cancels the finger transform), so they never follow the slider. To retent the *whole board* (thumb + wrist rest included), run retent.py (historical artifact, not included): `python3 retent.py <url-file> <tent°> [wrist-rest-tent°]`. With the stock thumb geometry the old OpenCascade crash at wrist-rest angles < 20° is gone — the canonical design runs **tent 12° / wrist 12°**. Bookmarks: **"Cosmos Cosmotyl — FINAL (tent 12°)"** (canonical) and **"Cosmos Cosmotyl — tent 25° twin"** (same design retented). Expert-mode paste remains broken upstream (crashes on any config, still worth reporting at [github.com/rianadon/Cosmos-Keyboards](https://github.com/rianadon/Cosmos-Keyboards)).
>
> Collision status: **zero errors, zero warnings** at both 12° and 25°. The wrist pad is moved (+52, 0, −18) mm from Cosmos's default: +52 mm X ends the pad at the middle-finger column line (support only needs to reach the index-column trace, per hand-fit review) which also clears the thumb cluster, and −18 mm Z keeps it from burying the thumb keycaps. The connector cutout is **USB only** (`usb-average`) — the default TRRS jack was removed since the ZMK/BT build needs no interconnect cable.

The viewer artifact shows the target geometry; these are the numbers it encodes, converted to Cosmos's units. Curvature is derived from each finger's measured comfortable travel (tighter arc for shorter travel):

| Column | Stagger vs middle (mm) | Splay | Row curvature |
|---|---|---|---|
| inner (index-far) | +9.8 | +10.7° | ~21°/key |
| index | +4.3 | +4.0° | ~23°/key |
| middle | 0 | 0° | ~15°/key |
| ring | +2.4 | −1.5° | ~16°/key |
| pinky | +15.2 | −11.4° | ~18°/key |
| outer | +15.2 | −11.4° | ~18°/key |

Column spread: index→middle 17.9, middle→ring 20.4, ring→pinky 21.2 mm. Tenting **12°** (canonical; a 25° twin is bookmarked if you want more tent). Enable Cosmos's **wrist rest** generation — it produces a separate STL sized to the case front. Export **STL** (print) + **STEP** (backup for CAD tweaks).

> [!IMPORTANT]
> In Cosmos, delete the extra bottom-row key from all columns except index/middle/ring — click keys to remove them in Advanced mode. The thumb cluster needs no edits: it is the stock **Curved, 3 keys** preset. Key count drives everything downstream (flex PCB lengths, ZMK matrix).

## Corrected keywell geometry (collision-verified)

Naive spacing collides on a concave MX keywell, so these constraints are baked into the generated case and the viewer, and verified by a 3D OBB separating-axis check over every keycap pair (frustum cap model: 18.3 mm base, 13 mm top) — **0 collisions**:

- **Row angular pitch is clearance-derived**: `Δθ = 18.9 mm / (R − 7 mm)`, because cap bases converge by factor (R−7)/R on a bowl of plate-radius R. This is why real Dactyls show gaps between rows.
- **Plate radii clamped to 55–75 mm** (per-finger from travel: index 55, middle 74, ring 67, pinky 60); anything tighter physically cannot clear MX caps.
- **Spreads widened over the raw scan** (index→middle 20.9, middle→ring 20.4, ring→pinky 22.7, pinky→outer 19 mm) so splay-converging near rows keep ≥1.7 mm cap clearance.
- **Thumb anchor at (−14, 57) mm** from the inner column origin, clearing the inner-bottom and index-extra keys.
- The outer column rides 3.6 mm forward of the pinky column — intentional, from cumulative splay (the pinky sweeps an arc to reach it).

## Final print files (Cosmos-generated) — print these

Exported straight from the final Cosmos session (open the **"Cosmos Cosmotyl — FINAL (tent 12°)"** bookmark to re-download or tweak; **"Cosmos Cosmotyl — tent 25° twin"** is the same design at 25°):

| File | Part |
|---|---|
| cosmotyl-caseright.stl (historical artifact, not included) / left (historical artifact, not included) | Main case (57k tris each) |
| cosmotyl-plateright.stl (historical artifact, not included) / left (historical artifact, not included) | Screw-on bottom plate |
| cosmotyl-holderright.stl (historical artifact, not included) / left (historical artifact, not included) | XIAO microcontroller holder |

- View them in cosmotyl_viewer.html (historical artifact, not included) — the exact meshes, both hands, orbit/zoom, now **including the wrist rests** (toggleable). The pad mesh (cosmotyl-wristright.stl (historical artifact, not included), 528 tris) was extracted from Cosmos's own three.js preview scene since the print-grade wrist STL is PRO-gated — its frame matches the case export exactly (x/y bboxes align to 0.01 mm), so it's positionally exact, just coarser than a print mesh.
- Hardware per Cosmos: **14× M3×6 mm countersunk screws + 14 heat-set inserts** (both hands total) fasten the plates.
- The **wrist rest** STL is PRO-gated in Cosmos — open the bookmark and export it there if you have PRO, or print without it first (the case stands on its walls). It's **130 mm max width with a 5° taper**, shifted **(+52, 0, −18) mm** from Cosmos's default: the +52 mm X retreat ends the pad at the middle-finger column line — palm support only needs to reach the index-column trace, and this also keeps it clear of the thumb cluster — while −18 mm Z stops it from crowding the thumb keycaps.
- The back wall has a **single USB cutout per half** (`usb-average`, fits most USB-C overmolds; `usb-slim` is snugger if you prefer). No TRRS — the BT build needs no interconnect.
- Total ≈ **149.8 m of filament** (~450 g) for everything at tent 12°; the 25° twin is 198.8 m (~590 g) because taller walls.

## Generated case files (SCAD fallback draft)

- dactyl_case.scad (historical artifact, not included) — parametric source (right half). Regenerate via gen_case.py (historical artifact, not included), which re-runs the collision check on every change.
- dactyl_case_right.stl (historical artifact, not included) — rendered mesh, verified **manifold and single-connected** (4322 triangles, one component).
- dactyl_case_left.stl (historical artifact, not included) — left hand, an exact X-mirror of the right (rendered via OpenSCAD `mirror()`, same 4322 facets), valid because the layout was derived from your right-hand scan and mirrored symmetrically.
- dactyl_stl_viewer.html (historical artifact, not included) — interactive three.js viewer of the **actual STL meshes** (both hands, orbit/zoom, gap slider, wireframe) — the exact geometry your slicer will see, embedded so it works offline.
- Features: 4 mm plates with **14.15 mm MX cutouts + 1.5 mm clip undercuts**, hulled web, world-vertical walls to the floor at 25° tent (stands on its own), USB-C and power-switch cutouts in the back wall, and a `fit_test()` coupon module — **print the coupon first** (2 min) and adjust `MX_HOLE` for your printer's shrink before committing to the full case.

````carousel

<!-- slide -->

<!-- slide -->

````

> [!NOTE]
> This SCAD case is a functional draft — correct geometry, cutouts, and stands at tent angle — but Cosmos still produces a more refined production case (rounded walls, screw bosses, bottom plate with feet). Recommended path: print the SCAD draft to validate reach/comfort cheaply, then transcribe the same numbers into Cosmos for the final.

## Electronics space (measured at 25° tent)

The web underside sits **~39 mm above the floor at the battery bay** (under the middle num row) and **~66 mm at the XIAO bay** (back wall, index side) on the 25° twin; at the canonical 12° tent the case is lower, but clearance still dwarfs the parts — the tallest component stack is the 5.6 mm LiPo, and even the shallow thumb-side walls exceed that. Mount the battery on the floor with VHB tape near the tall inner side; mount the XIAO against the back wall aligned to the USB-C cutout.

## Electronics: the pin budget is a perfect fit

The **XIAO nRF52840 exposes exactly 11 GPIOs (D0–D10)**, and your matrix needs exactly **6 columns + 5 rows = 11 pins** — zero pins wasted, no expander needed. The 3 thumb keys wire into the unused row-5 positions of the inner, index, and pinky columns, so 29 keys fit a 5×6 matrix with one hole.

| XIAO pin | Function |
|---|---|
| D0–D5 | col0–col5 (inner→outer) |
| D6–D10 | row0–row4 (num→extra/thumb) |
| BAT+/BAT− pads (underside) | LiPo — charger is built in |

Battery sensing uses the XIAO's internal divider (no GPIO cost); ZMK supports it out of the box. You have 8 XIAOs = 2 per keyboard + 6 spares/prototypes.

## Column flex PCBs — two real options

Per-column flexible strips with hotswap sockets + per-key diodes pre-soldered; you bend them into the keywell curvature, so soldering shrinks to ~11 wires per half:

1. **Pumpkin Patch PCBs** (Cosmos-native, from the Cosmos/Lemon store): fully interconnected flex columns with FPC ribbon tails and RGB. Designed for zero-solder use with the **Lemon** microcontroller's FPC connectors. With a XIAO instead, you either solder the tail pads directly or add a **Skree translator** board (FPC connector → plain pads). Cosmos generates matching PCB cutouts in the case when you select them.
2. **Skree flex PCBs** ([skree.us](https://skree.us)): column strips with plain solder pads — 1 column wire per strip + daisy-chained row wires across strips. No adapter needed for the XIAO; slightly more soldering (~17 joints/half), which is still trivial next to handwiring 58 diodes.

**Decision (made): Skree strips + XIAO, MX switches.** This skips the Lemon/translator dependency, your soldering background makes 17 joints a non-issue, and every part is orderable today.

> [!WARNING]
> Column flex PCBs are overwhelmingly **MX hotswap**. The choc-spacing argument from the flat-PCB plan no longer applies — the keywell curvature is what solves your index finger's short 33.8 mm travel — so build MX and pick from the whole switch market.

## ZMK config sketch

Board is upstream in ZMK as `seeeduino_xiao_ble`; you write a shield:

```
# build.yaml
include:
  - board: seeeduino_xiao_ble
    shield: yushi_dactyl_left
  - board: seeeduino_xiao_ble
    shield: yushi_dactyl_right
```

```dts
/* yushi_dactyl.dtsi — kscan + matrix transform */
kscan0: kscan {
    compatible = "zmk,kscan-gpio-matrix";
    diode-direction = "col2row";   /* verify against strip silkscreen */
    col-gpios = <&xiao_d 0 GPIO_ACTIVE_HIGH>, ...;  /* D0-D5 */
    row-gpios = <&xiao_d 6 (GPIO_ACTIVE_HIGH | GPIO_PULL_DOWN)>, ...;  /* D6-D10 */
};
```

Left half = central (`zmk,split-role = central` via shield defconfig), right = peripheral. Adapt an existing keymap to the final matrix.

## BOM (both hands)

| Part | Qty | Est. cost |
|---|---|---|
| Cosmos case + wrist rest prints (PETG, ~450 g) | 2+2 | ~\$15 filament |
| Seeed XIAO nRF52840 | 2 | already owned (×8) |
| Column flex PCB strips (4-key ×8, 5-key ×4) + 6 single thumb sockets | 12+6 | \$35–60 |
| MX hotswap switches | 58 | \$25–45 |
| LiPo 601230–502030 (250–400 mAh), JST or direct-solder | 2 | \$10–14 |
| Power slide switch + M3 heat-set inserts + screws | 2 sets | ~\$8 |
| Keycaps (MT3/DSA blank recommended for keywells) | 58 | \$30–60 |

## Build order

1. Print **one right-half case in PLA** at the 12° tent; dry-fit switches in the well, live-test reach on all 5 index/middle/ring rows for a few days.
2. Iterate curvature/stagger in Cosmos if any column feels off (each reprint ≈ \$2, overnight).
3. When the shape is right: print both halves + wrist rests in PETG, install flex strips + XIAOs + batteries, flash ZMK.
4. Keep a familiar keyboard available while evaluating the prototype.

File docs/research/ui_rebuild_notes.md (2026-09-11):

# UI reconstruction notes — "from scratch via Advanced menu" (2026-09-07)

> Historical design notes. Some experiments and referenced artifacts are not
> included in this repository; see the root README for the current build.

## Goal
Rebuild Cosmotyl by driving Cosmos's real UI from the default keyboard, so all
pose relationships (esp. tent ↔ thumb cluster) are UI-owned and every slider
keeps working. Minimum deviation from stock.

## Why
User set Tenting 25°→12° in our encoded design and the thumb cluster
disconnected: our `thumbs_cluster()` bakes Ry(25°) into the thumb's absolute
pose, the UI only re-poses the fingers cluster.

## Target deltas from stock (everything else stays default)
1. 6 columns × 4 rows fingers; extra bottom-row key on middle+ring only
2. Thumb: builtin Curved preset, Number of Keys = 3
3. Part: MX + Skree flex PCB; XIAO nRF52840 (wireless); usb connector default
4. Tenting 25° (via the UI field so it stays live-editable)
5. Wrist rest on, widened (130mm max width, 5° taper)
6. Splay: inner +10.7, index +4.0, middle 0, ring −1.5, pinky −11.4, outer −11.4
   — via Advanced per-column splay if exposed, else Expert menu (user's ask).
   NOTE upstream bug: expert-mode PASTE crashes; small in-editor edits untested.
7. (Dropped for min-deviation: per-column custom stagger/curvature from scan)

## Facts learned
- (fill in as we go)

## State
- Step 1: inventory Advanced-mode controls on the DEFAULT keyboard.

## Session: keycap-wall issue hunt (2026-09-07 evening)

**Offender identified**: the 2 "keycap intersects walls at 3.6mm press" issues are a
THUMB keycap (per hand). Clicked the red cap → Edit Key shows fractional Row -0.06 /
Col 1.43, custom pose (-15.2, -9.9, 5) rot (10.5, -18.2, 2.2) = Curved-preset thumb key.

**Rejected levers** (issue count unchanged or worse):
- KeyboardExtra.web_min_thickness_factor 0.8→0.5 (field 1, float): no change, +2 benign; filament 192.5→188.9.
- Wall Z Offset 15→18 (kbd field 18=180): BREAKS wrist-rest wall locator (same failure wallXY-5 had).
- Wall XY 7→9 (field 17=90): generates fine, no issue change, +6m filament.
- Thumb H/V spacing 20→22 via UI inputs: WORSE (4 keycap-wall + 2 keycap-keycap).

**Root cause found by diffing old (cosmos_cm_url.txt, 229.5m, CLEAN: only 2 benign) vs new
(noprof, 192.5m)**: thumb KEYS byte-identical; cluster-level differs:
- field 4 block: OLD (1:220, 2:185, 3:1349, 4:0) = H 22 / V 18.5 / f3 1349(-15°?); NEW (200,200,0,0,+f6/f7=0)
- field 8 position: OLD 6236506098339 vs NEW 1705169061323
- field 9 rotation: OLD 25151491212243 vs NEW 27058591172781

**Fix strategy**: transplant old field 4 only (keep UI pose → tent-slider safe). If dirty,
transplant 4+8+9 (full old thumb) and re-run tent 25→12 acceptance test.

**ui_step.js gained `click x y`** (Input.dispatchMouseEvent). Banner must be COLLAPSED
before canvas clicks (expanded banner eats clicks). Edit Key tab at ~(1435,646).

## Session: thumb-doesn't-follow-tenting (2026-09-09)

User: "change tent to 12 → thumb clusters remain in place. Not what I wanted."

**Root cause is UPSTREAM Cosmos behavior, not our transplant:**
- Experiment: noprof (pure UI-built) tent 25→12 via UI → fingers rot 1165824→571392, thumb pose
  bytes UNCHANGED (8:1705169061323, 9:27058591172781).
- Stock keyboard (no #cm), tent 0→20 via UI → same: thumb pose identical to preset default;
  screenshot stock_tent20_clear.png (local capture, not included) shows stock thumb visibly staying flat.
- Source: config.cosmos.ts calcClusterTrsf = thumbPose ∘ fingerPosInv(inFlat=T) ∘ fingerPos(inFlat=F);
  the inv/fwd pair cancels in 3D ⇒ serialized thumb poses are ABSOLUTE world-space.
  Tenting Angle input rewrites ONLY fingers rotation [0, deg*45, 0].

**Fix: scratch/retent.py <url|file> <tent_deg> [wr_tent_deg]**
- Rewrites fingers rot; rotates thumb pose by Ry(Δ) about fingers position (pos AND rot,
  Euler order R = Rz(g)·Ry(b)·Rx(a), X applied first); sets KeyboardExtra field 14 (WR tenting ×45).
- Validation: retent 25→25 reproduces canonical URL byte-identical.
- retent 25→12: thumb VISIBLY follows tent (looks right), 2 benign notices only, filament 164.2m.

**Wrist-rest tenting fragility (OpenCascade error 24454592 "During processing of Wrist Rest"):**
- board 12 / WR 12: FAILS (reproducible, 2 gens)
- board 12 / WR 15: FAILS
- board 12 / WR 25: WORKS (164.2m)
- board 25 / WR 25: works (canonical)
- Guidance: keep WR tenting high (≈25°) or adjust via UI input after loading; if wrist gen
  fails, raise the 3rd retent arg.

---

## Session: stock thumb swap → FINAL design (tent 12/WR 12, USB-only)

**Thumb cluster replaced with stock "Curved, 3 keys" preset + nudge.**
- Byte-diff vs noprof: canonical differed ONLY in thumb fields 4 (spacing 22/18.5 vs 20/20) and 8/9 (pose).
- Stock preset as-is: 1 real keycap-wall error/hand. Nudge via scratch/move_thumb.py:
  (-2,-3,0) cleared reals; **(-4,-6,0) = zero errors zero warnings** (locked).

**WR fragility note above is OBSOLETE:** board 12 / WR 12 now WORKS — the OpenCascade
crash was tied to the OLD custom thumb geometry, not the WR angle itself. With the stock
thumb, retent.py 12/12 renders clean (149.7m pre-pad-fix).

**Wrist pad (field 15) empirical map:**
- position moves the pad body; Z honored. maxWidth (extra f11/f17) trims OUTER/pinky edge
  only; extension (extra f9/f16) is the FRONT edge; the case-side edge is ALWAYS conformal
  (generator is PRO/closed-source) — cannot be detached.
- Interference fixes that FAILED: thumb +6Y (4 real errors), pad -8Y, maxWidth cut, ext=0.
- Fix that WORKED: pad (+52, 0, -18) mm — +52 X ends pad at middle-column line (user spec:
  support only to the index-column trace), -18 Z clears thumb keycaps. move_wrist.py.

**Connectors (keyboard field 16):** 0402 (trrs+usb-average) → 02 (usb-average only).
Verified single slot per half in back-wall render. MCU holder unaffected (sized by MCU=74).

**Promotion (this date):** final URL → cosmos_cm_url{,_final,_t12}.txt; 25° twin via
retent.py 25/25 → cosmos_cm_url_t25.txt (198.8m, clean). Filament: 149.8m @ 12°.
Both bookmarks updated; 6 STLs re-exported; viewer rebuilt.

**Wrist-rest mesh extraction (viewer request):** the print STL is PRO-gated, but the
preview geometry lives in the page's three.js scene. Technique (scratch/extract_wrist.js):
inject `window.__THREE_DEVTOOLS__ = new EventTarget()` via Page.addScriptToEvaluateOnNewDocument
(captures 'observe' events -> renderer), wrap renderer.render to harvest the scene, traverse
meshes. Cosmos scene: ~190 meshes; keycaps 2380/932 tris; per-half hidden source group holds
case(3640t)/web(6080t)/plate-ish(1100t)/WRIST(528t)/floor(1122t)/holder(11512t); display
copies are parented under matrixWorld scale ±0.00322 (x negated = left mirror).
KEY FACT: raw geometry buffers are in mm in the EXACT same frame as the STL exports
(case raw bbox == caseright.stl bbox in x/y; z shifted +44.02 because export re-floors z=0).
So: grab buffers (base64 via CDP), apply z+=44.02, write binary STL -> cosmotyl-wristright.stl
(85.2 x 109.8 x 38.1 mm). Embedded in viewer with "Show wrist rests" toggle; left = x-mirror.
mesh_json_to_stl.py converts grabbed JSON generically (matrixWorld path also available).

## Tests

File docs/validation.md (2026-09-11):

# Geometry validation

Validated with Python 3.14.7, Manifold 3.5.3, and independent OpenSCAD 2021.01
STL re-import checks on macOS. CI also runs the build on Python 3.10 and 3.14.

## Screw-cutout repair

The original vertical counterbores broke through several sloping webs, leaving
missing portions of the screw-head bearing surface. The repair adds explicit
flat pads (radius 3.3 mm, 3.4 mm thick) around the 3.4 mm shaft clearances,
while preserving the 6 mm counterbores. Heads sit 0.4 mm lower than before.
Matching base columns are revolved as single solids and stop 0.15 mm below
each pad underside, with blind
pilot bores leaving at least 1 mm of base material.

Plate/web joins are inset 0.1 mm from plate edges and 0.02 mm from their upper
and lower faces to avoid coincident face remnants. Clip relief cuts extend
below the plate instead of ending exactly on its lower face. A 0.05 mm
clearance envelope removes small intrusions into the modeled switch volume.

The v4 build uses Manifold on the same literal geometry that it writes to
SCAD, then validates the serialized binary STL files. This avoids the fragile
CGAL export path in OpenSCAD 2021.01; see the upstream
[quantization discussion](https://github.com/openscad/openscad/issues/4969).
OpenSCAD remains useful for viewing the generated SCAD and independently
checking the final STL geometry.

## Required checks

- No OBB collisions in the default 29-key layout.
- Every printed STL has two consistently oriented incident faces per edge,
  no degenerate triangles, and the expected component count: two for the
  assembled top, one each for the base and the individual print files.
- All seven screw shafts are open. At three radii and 64 angles per radius,
  each bearing ring has a flat upper seat and at least 1.5 mm of material.
- Column-top probes match each pad underside with a 0.15 mm gap.
- Top/switch, base/switch, top/base, and all seven screw-head/switch
  intersections are empty. These checks use the serialized meshes.
- The three print files rest at Z=0. The finger sheet and pod retain the
  selected −90° rotation about Y.
- The offline viewer rebuilds from the current example meshes and exposes
  the top and base independently. Five obsolete v1/v3 STL files were removed.

## Remaining limitations

The print-orientation heuristic reports one unresolved finger-sheet patch
(approximately 810 mm²). These geometric checks do not establish physical
print quality, comfort, strength, or assembly fit with real hardware.
Electronics mounting and the v4 wrist rest remain unfinished.

Personal hand analysis remains excluded, and the release retains the
three.js license notice and fully offline viewer resources.

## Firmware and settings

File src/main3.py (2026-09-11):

"""v3: floating plates. Steps: (1) lay out keys as full plates, (2) loft
adjacent side faces flush (web.py posts sit exactly on plate edges), (3) cut
holes. The thumb pod floats — no surface connection to the board — and both
bodies stand on vertical rods anchored in a flat bottom shell.

Usage: python3 main3.py [--fast]
"""
import math
import sys
import os
from pathlib import Path

from render import render, openscad

from config import CASE, COLUMNS, THUMB
from devtool import devtool_scad
from placement import Layout
from transform import apply, scad_mat
from verify import report
from web import HD, HW, get, post

OUT_SCAD = 'case3_right.scad'
OUT_STL = 'case3_right.stl'
ROD_R = 3.0          # rod radius (Ø6)
EMBED = 1.5          # rod overlap into the plate/web underside for CSG fusion


def _plate(m):
    return (f'multmatrix({scad_mat(m)}) translate([0,0,{-CASE.plate_t / 2}]) '
            f'cube([{CASE.key_w},{CASE.key_d},{CASE.plate_t}], center=true);')


def _holes(m):
    # Extend the clip relief below the plate to avoid a coincident bottom face.
    # Its upper ledge stays 1.5 mm above the plate underside.
    mm = scad_mat(m)
    return (f'multmatrix({mm}) translate([0,0,{-CASE.plate_t / 2}]) '
            f'cube([{CASE.mx_hole},{CASE.mx_hole},{CASE.plate_t + 2}], center=true);'
            f'multmatrix({mm}) translate([0,0,{-CASE.plate_t + 0.25}]) '
            f'cube([{CASE.mx_hole + CASE.clip_undercut},'
            f'{CASE.mx_hole + CASE.clip_undercut},2.5], center=true);')


def finger_webs(layout, surface_inset=0.0, edge_inset=0.0):
    """Row/col/diagonal lofts between finger keys only (no thumb bridge)."""
    def corner(m, sx, sy):
        return post(m, sx, sy, surface_inset, edge_inset)

    out = []
    for c in range(len(COLUMNS)):
        for r in range(max(col.rows for col in COLUMNS)):
            A = get(layout, c, r)
            if A is None:
                continue
            Rt = get(layout, c + 1, r)
            Dn = get(layout, c, r + 1)
            Dg = get(layout, c + 1, r + 1)
            if Rt:
                out.append('hull() {%s%s%s%s}' % (corner(A, HW, HD), corner(A, HW, -HD),
                                                  corner(Rt, -HW, HD), corner(Rt, -HW, -HD)))
            if Dn:
                out.append('hull() {%s%s%s%s}' % (corner(A, -HW, -HD), corner(A, HW, -HD),
                                                  corner(Dn, -HW, HD), corner(Dn, HW, HD)))
            corners = [(A, HW, -HD)]
            if Rt:
                corners.append((Rt, -HW, -HD))
            if Dn:
                corners.append((Dn, HW, HD))
            if Dg:
                corners.append((Dg, -HW, HD))
            if len(corners) >= 3:
                out.append('hull() {' + ''.join(corner(m, sx, sy) for m, sx, sy in corners) + '}')
    return out


def pod_webs(layout, surface_inset=0.0, edge_inset=0.0):
    """Lofts between adjacent thumb keys only."""
    def corner(m, sx, sy):
        return post(m, sx, sy, surface_inset, edge_inset)

    t = [layout.thumb_frame(i) for i in range(THUMB.keys)]
    return ['hull() {%s%s%s%s}' % (corner(t[i], -HW, HD), corner(t[i], -HW, -HD),
                                   corner(t[i + 1], HW, HD), corner(t[i + 1], HW, -HD))
            for i in range(THUMB.keys - 1)]


FLAT_TILT = 42.0     # deg; undersides flatter than this need anchors (45 - margin)


def _tilt(m):
    """Underside tilt from horizontal (deg): 0 = flat overhang, 90 = vertical."""
    return math.degrees(math.acos(min(1.0, abs(m[2][2]))))


def _rod(x, y, z_top):
    return (f'translate([{x:.2f},{y:.2f},0.5]) '
            f'cylinder(h={z_top - 0.5:.2f}, r={ROD_R}, $fn=32);')


def rods(layout):
    """Support-free rod distribution [print audit 2026-09-10]:

    Every underside flatter than FLAT_TILT is an unprintable overhang, and the
    only places a Ø6 rod fits under the board are 4-key junctions (radial
    clearance 3.36mm to the housing diagonals) and outboard of boundary edges
    (interior edge gaps are 4.5mm < Ø6). So: a junction rod at every interior
    junction touching a flat key, plus an outboard edge rod on every boundary
    edge of a flat key. Max unanchored bridge = pitch - Ø6 ≈ 12.5mm.
    """
    out, pts = [], []

    def junction(frames_corners):
        ps = [apply(m, (sx, sy, -CASE.plate_t)) for m, sx, sy in frames_corners]
        x = sum(p[0] for p in ps) / len(ps)
        y = sum(p[1] for p in ps) / len(ps)
        z = min(p[2] for p in ps)
        return x, y, z

    def edge_rod(m, sx, sy, tag):
        p = apply(m, (sx, sy, -CASE.plate_t))
        out.append(_rod(p[0], p[1], p[2] + 1.2))
        pts.append((tag, 0, 0, p[0], p[1], p[2]))

    # Interior 4-key junction rods wherever a flat key touches the junction.
    for c in range(len(COLUMNS) - 1):
        for r in range(max(COLUMNS[c].rows, COLUMNS[c + 1].rows)):
            A, B = get(layout, c, r), get(layout, c + 1, r)
            C, D = get(layout, c, r + 1), get(layout, c + 1, r + 1)
            if not (A is not None and B is not None
                    and C is not None and D is not None):
                continue
            if min(_tilt(A), _tilt(B), _tilt(C), _tilt(D)) >= FLAT_TILT:
                continue
            x, y, z = junction([(A, HW, -HD), (B, -HW, -HD),
                                (C, HW, HD), (D, -HW, HD)])
            out.append(_rod(x, y, z + EMBED))
            pts.append(('board', c, r, x, y, z))

    # Outboard edge rods on every boundary edge of a flat finger key.
    for c in range(len(COLUMNS)):
        for r in range(COLUMNS[c].rows):
            m = get(layout, c, r)
            if _tilt(m) >= FLAT_TILT:
                continue
            if c == 0 or get(layout, c - 1, r) is None:
                edge_rod(m, -HW - 1.0, 0.0, f'edgeL{c}{r}')
            if get(layout, c + 1, r) is None:
                edge_rod(m, HW + 1.0, 0.0, f'edgeR{c}{r}')
            if r == 0:
                edge_rod(m, 0.0, HD + 1.0, f'edgeB{c}{r}')
            if get(layout, c, r + 1) is None:
                edge_rod(m, 0.0, -HD - 1.0, f'edgeF{c}{r}')

    # Thumb pod: junction rods between pairs + outboard ring (all keys flat).
    t = [layout.thumb_frame(i) for i in range(THUMB.keys)]
    for i in range(THUMB.keys - 1):
        x, y, z = junction([(t[i], -HW, HD), (t[i], -HW, -HD),
                            (t[i + 1], HW, HD), (t[i + 1], HW, -HD)])
        out.append(_rod(x, y, z + EMBED))
        pts.append(('podJ', i, i + 1, x, y, z))
    edge_rod(t[0], HW + 1.0, 0.0, 'pod0R')
    edge_rod(t[THUMB.keys - 1], -HW - 1.0, 0.0, 'pod2L')
    for i in range(THUMB.keys):
        edge_rod(t[i], 0.0, -HD - 1.0, f'podF{i}')
        edge_rod(t[i], 0.0, HD + 1.0, f'podB{i}')
    return out, pts


def _hull2d(pts):
    """Andrew monotone chain; returns CCW convex hull of 2D points."""
    pts = sorted(set((round(x, 2), round(y, 2)) for x, y in pts))
    if len(pts) <= 2:
        return pts

    def cro(o, a, b):
        return (a[0] - o[0]) * (b[1] - o[1]) - (a[1] - o[1]) * (b[0] - o[0])

    lo, up = [], []
    for p in pts:
        while len(lo) >= 2 and cro(lo[-2], lo[-1], p) <= 0:
            lo.pop()
        lo.append(p)
    for p in reversed(pts):
        while len(up) >= 2 and cro(up[-2], up[-1], p) <= 0:
            up.pop()
        up.append(p)
    return lo[:-1] + up[:-1]


def footprint_poly(layout, rod_pts):
    """Convex hull of the XY projection of every solid: all plate corners
    (top and bottom faces of finger + thumb plates; webs are hulls of these
    same corners so they project inside) plus each rod's base circle."""
    pts = []
    hw, hd = CASE.key_w / 2, CASE.key_d / 2
    for _, m in layout.items():
        for sx in (-hw, hw):
            for sy in (-hd, hd):
                for sz in (0.0, -CASE.plate_t):
                    p = apply(m, (sx, sy, sz))
                    pts.append((p[0], p[1]))
    for _, _, _, x, y, _ in rod_pts:
        for k in range(12):
            a = k * math.pi / 6
            pts.append((x + ROD_R * math.cos(a), y + ROD_R * math.sin(a)))
    return _hull2d(pts)


def build(layout):
    fplates, fholes, tplates, tholes = [], [], [], []
    for c in range(len(COLUMNS)):
        for r in range(COLUMNS[c].rows):
            m = layout.key_frame(c, r)
            fplates.append(_plate(m))
            fholes.append(_holes(m))
    for i in range(THUMB.keys):
        m = layout.thumb_frame(i)
        tplates.append(_plate(m))
        tholes.append(_holes(m))

    body = ('difference() { union() {' + ' '.join(fplates + finger_webs(layout)) +
            '} ' + ' '.join(fholes) + '}')
    pod = ('difference() { union() {' + ' '.join(tplates + pod_webs(layout)) +
           '} ' + ' '.join(tholes) + '}')
    rod_scads, rod_pts = rods(layout)
    for tag, a, b, x, y, z in rod_pts:
        print(f'rod {tag:5s} ({a},{b}) at ({x:7.2f},{y:7.2f}) top z={z:6.2f}')
    poly = footprint_poly(layout, rod_pts)
    pstr = ', '.join(f'[{x:.2f},{y:.2f}]' for x, y in poly)
    shell = (f'linear_extrude({CASE.bottom_t}) offset(r=2.5) '
             f'polygon([{pstr}]);')

    scad = ('// v3: floating plates + pod on rods over a bottom shell\n'
            'union() {\n' + body + '\n' + pod + '\n' +
            ' '.join(rod_scads) + '\n' + shell + '\n}\n')
    open(OUT_SCAD, 'w').write(scad)
    uncut = ('// v3 uncut loft reference (steps 1-2, before hole cuts)\n'
             'union() {' + ' '.join(fplates + finger_webs(layout) +
                                    tplates + pod_webs(layout)) + '}\n')
    open('uncut3_right.scad', 'w').write(uncut)
    open('devtool_right.scad', 'w').write(devtool_scad(layout))
    print(f'wrote {OUT_SCAD} + uncut3_right.scad')


def main():
    layout = Layout()
    if report(layout):
        sys.exit('verification failed; not rendering')
    build(layout)
    if '--fast' in sys.argv:
        return
    render(OUT_SCAD, OUT_STL)
    from stl_clean import clean
    ncomp, dropped = clean(OUT_STL)
    print(f'wrote {OUT_STL} ({ncomp} raw components; dropped {dropped} tris)')
    render('devtool_right.scad', 'devtool_right.stl')
    open('interference3.scad', 'w').write(
        'intersection() { import("case3_right.stl"); '
        'import("devtool_right.stl"); }\n')
    render('interference3.scad', 'interference3.stl', expect_empty=True)


if __name__ == '__main__':
    os.chdir(Path(__file__).resolve().parent)
    main()

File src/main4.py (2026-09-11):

"""v4: two-piece print (design A). Top sheet = plates + webs + pod, printed on
its side (row-arc normals live in the y-z plane, so a 90-deg roll about y turns
every flat underside into a near-vertical wall). Base = flat convex-hull shell
+ 7 columns ending in Ø6 necks with thread-forming pilot bores; the rods print
WITH the base, standing vertically. Assembly: 7 coarse thread-forming screws
(PT/plastite 3.0 x 12, pan head) dropped in from above BEFORE switches are
clipped in — heads recess below the plate top because upper housings leave
only 2.23mm radial clearance at junctions.

Usage: python3 main4.py [--fast]
"""

import math
import sys
import os
from pathlib import Path

from stl_io import read_stl, write_stl
from mesh_audit import topology, screw_seats, column_seats

from config import CASE, COLUMNS, THUMB
from devtool import devtool_scad
from main3 import _holes, _plate, finger_webs, footprint_poly, pod_webs
from placement import Layout
from transform import apply
from verify import report
from web import HD, HW, get

TOP_SCAD, TOP_STL = "top4_right.scad", "top4_right.stl"
BASE_SCAD, BASE_STL = "base4_right.scad", "base4_right.stl"

# PT 3.0 thread-forming screw in plastic: Ø2.5 pilot, Ø6 boss minimum (2xd),
# Ø3.4 clearance, pan head Ø5.6 x 2.4.
PILOT_R = 1.25
CLEAR_R = 1.7
CBORE_R = 3.0  # Ø6.0 counterbore: 5.6 head + 0.4; keeps 0.26mm web to the
HEAD_CLEARANCE = 0.4  # recess screw heads below adjacent moving-key envelopes
HEAD_H = 2.4  # MX hole corner (junction->hole-corner clearance 3.26mm)
NECK_R = 3.0  # Ø6 neck fits the 3.36mm junction channel
BODY_R = 4.5  # Ø9 column body below the housing zone
NECK_H = 5.0  # housing keep-out reaches only 0.8mm below underside
FLARE_H = 1.5  # 45-deg cone neck->body
SEAT_R = 3.3  # continuous bearing pad around the Ø3.4 screw clearance
SEAT_DROP = 1.5  # extend below the lowest junction corner
SEAT_GAP = 0.15  # conformal seat clearance (subtract sheet lowered by this)

WEB_SURFACE_INSET = 0.02
WEB_EDGE_INSET = 0.10

BOARD_J = [(0, 0), (0, 2), (2, 3), (4, 0), (4, 2)]


def _junction(frames_corners):
    ps = [apply(m, (sx, sy, -CASE.plate_t)) for m, sx, sy in frames_corners]
    x = sum(p[0] for p in ps) / len(ps)
    y = sum(p[1] for p in ps) / len(ps)
    z = min(p[2] for p in ps)
    return x, y, z


def column_pts(layout):
    """(tag, x, y, z_underside_min) for the 5 board + 2 pod screw columns."""
    pts = []
    for c, r in BOARD_J:
        A, B = get(layout, c, r), get(layout, c + 1, r)
        C, D = get(layout, c, r + 1), get(layout, c + 1, r + 1)
        x, y, z = _junction([(A, HW, -HD), (B, -HW, -HD), (C, HW, HD), (D, -HW, HD)])
        pts.append((f"J{c}{r}", x, y, z))
    t = [layout.thumb_frame(i) for i in range(THUMB.keys)]
    for i in range(THUMB.keys - 1):
        x, y, z = _junction(
            [(t[i], -HW, HD), (t[i], -HW, -HD), (t[i + 1], HW, HD), (t[i + 1], HW, -HD)]
        )
        pts.append((f"P{i}{i + 1}", x, y, z))
    return pts


def build(layout):
    fplates, fholes, tplates, tholes = [], [], [], []
    for c in range(len(COLUMNS)):
        for r in range(COLUMNS[c].rows):
            m = layout.key_frame(c, r)
            fplates.append(_plate(m))
            fholes.append(_holes(m))
    for i in range(THUMB.keys):
        m = layout.thumb_frame(i)
        tplates.append(_plate(m))
        tholes.append(_holes(m))

    cols = column_pts(layout)
    for tag, x, y, z in cols:
        print(
            f"col {tag:4s} at ({x:7.2f},{y:7.2f}) underside z={z:6.2f} "
            f"seat z={z + CASE.plate_t - HEAD_H - HEAD_CLEARANCE:6.2f}"
        )

    # Flat bearing pads prevent the counterbore from breaking through a sloped
    # web. The base columns terminate below each pad underside.
    pads = []
    for tag, x, y, z in cols:
        seat = z + CASE.plate_t - HEAD_H - HEAD_CLEARANCE
        pads.append(
            f"translate([{x:.5f},{y:.5f},{z - SEAT_DROP:.5f}]) "
            f"cylinder(h={seat - z + SEAT_DROP:.5f}, r={SEAT_R}, $fn=64);"
        )

    # --- top sheet: (plates+webs - key holes) - screw clearance/counterbores
    screw_cuts = []
    for tag, x, y, z in cols:
        seat = z + CASE.plate_t - HEAD_H - HEAD_CLEARANCE
        screw_cuts.append(
            f"translate([{x:.5f},{y:.5f},{z - 20:.5f}]) "
            f"cylinder(h=40, r={CLEAR_R}, $fn=32);"
        )
        screw_cuts.append(
            f"translate([{x:.5f},{y:.5f},{seat:.5f}]) "
            f"cylinder(h=30, r={CBORE_R}, $fn=32);"
        )
    body = (
        "difference() { union() {"
        + " ".join(
            fplates
            + finger_webs(
                layout, surface_inset=WEB_SURFACE_INSET, edge_inset=WEB_EDGE_INSET
            )
        )
        + "} "
        + " ".join(fholes)
        + "}"
    )
    pod = (
        "difference() { union() {"
        + " ".join(
            tplates
            + pod_webs(
                layout, surface_inset=WEB_SURFACE_INSET, edge_inset=WEB_EDGE_INSET
            )
        )
        + "} "
        + " ".join(tholes)
        + "}"
    )
    top = (
        "// v4 top sheet: print on its side (see main4.py header)\n"
        "difference() { union() {\n"
        + body
        + "\n"
        + pod
        + "\n"
        + " ".join(pads)
        + "\n} "
        + " ".join(screw_cuts)
        + devtool_scad(layout, clearance=0.05)
        + "}\n"
    )
    open(TOP_SCAD, "w").write(top)

    # --- base: shell + columns ending below the flat bearing pads;
    # revolve each column as one solid, then subtract the pilot bores.
    col_solids, pilots = [], []
    for tag, x, y, z in cols:
        ztop = z - SEAT_DROP - SEAT_GAP  # flat column seat beneath the bearing pad
        profile = [
            (0, 0.5),
            (BODY_R, 0.5),
            (BODY_R, ztop - NECK_H - FLARE_H),
            (NECK_R, ztop - NECK_H),
            (NECK_R, ztop),
            (0, ztop),
        ]
        points = ", ".join(f"[{r:.5f},{h:.5f}]" for r, h in profile)
        col_solids.append(
            f"translate([{x:.5f},{y:.5f},0]) "
            f"rotate_extrude($fn=48) polygon([{points}]);"
        )
        pilot_bottom = max(1.0, ztop - 10.0)
        pilots.append(
            f"translate([{x:.5f},{y:.5f},{pilot_bottom:.5f}]) "
            f"cylinder(h={ztop - pilot_bottom + 1.0:.5f}, r={PILOT_R}, $fn=24);"
        )
    rodlike = [(t, 0, 0, x, y, z) for t, x, y, z in cols]
    poly = footprint_poly(layout, rodlike)
    pstr = ", ".join(f"[{x:.5f},{y:.5f}]" for x, y in poly)
    shell = f"linear_extrude({CASE.bottom_t}) offset(r=2.5, $fn=32) polygon([{pstr}]);"
    base = (
        "// v4 base: shell + screw columns (prints flat, rods vertical)\n"
        "difference() { union() {\n"
        + shell
        + "\n"
        + " ".join(col_solids)
        + "\n} "
        + " ".join(pilots)
        + "}\n"
    )
    open(BASE_SCAD, "w").write(base)
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

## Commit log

2026-09-11 Publish sanitized Cosmotyl prototype with reliable build checks
    [base4_right.stl, bottom_right.stl, case3_right.stl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]
2026-09-11 Repair screw bearing seats and generate closed v4 meshes
    [base4_right.stl, bottom_right.stl, case3_right.stl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]
